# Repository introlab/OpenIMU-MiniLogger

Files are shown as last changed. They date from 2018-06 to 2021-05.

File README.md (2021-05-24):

# OpenIMU-MiniLogger
OpenIMU - Open Hardware Mini Logger based on ESP32. 

Please see also :
[OpenIMU](https://github.com/introlab/OpenIMU) Compatible Sofware.

# Authors
* Dominic Létourneau
* Vincent-Philippe Rhéaume
* Cédric Godin
* Philippe-Olivier Provost
* François Michaud
* Simon Brière
* Mathieu Hamel
* Thomas Godel
* Philippe Boulet

# Pictures
## PCB

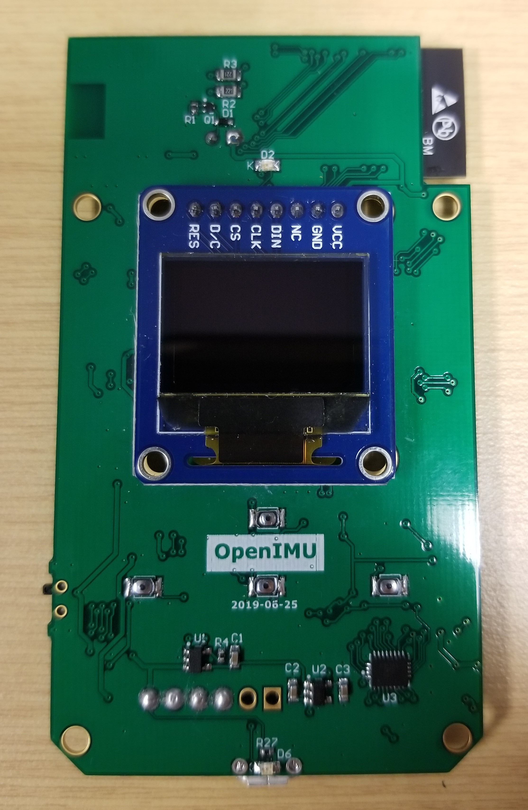
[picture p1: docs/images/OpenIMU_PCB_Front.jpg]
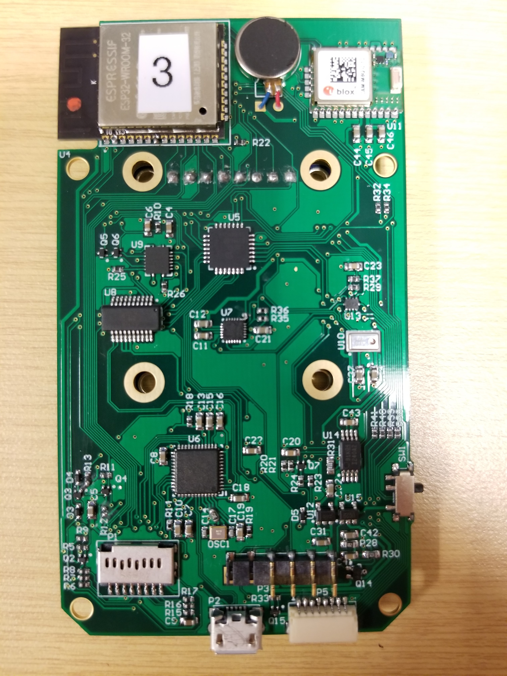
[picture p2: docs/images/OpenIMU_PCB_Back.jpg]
  

## Case and ports

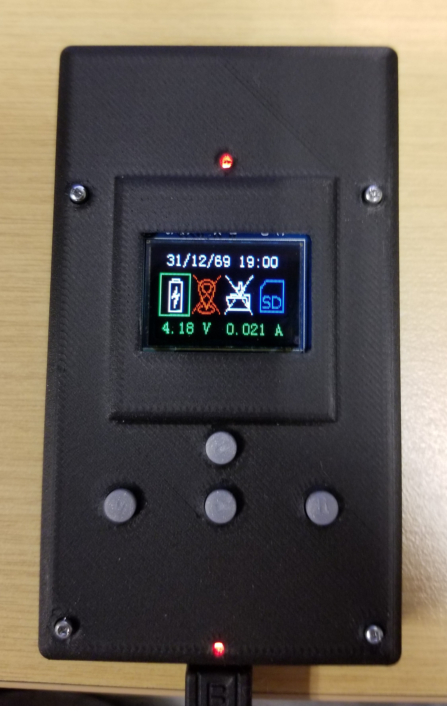
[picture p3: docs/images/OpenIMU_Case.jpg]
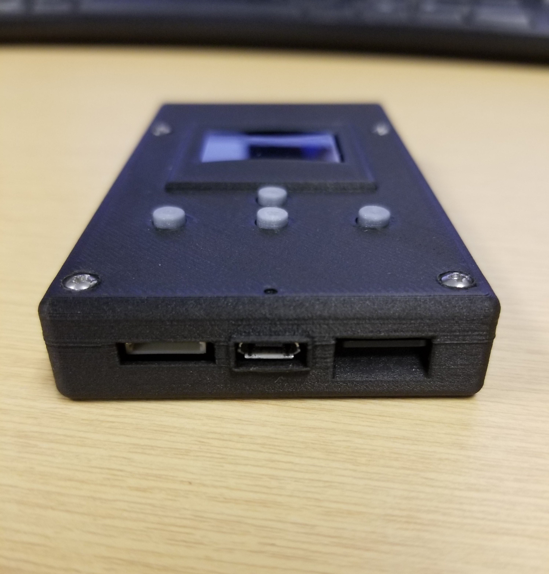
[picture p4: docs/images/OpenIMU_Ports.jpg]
  

## Starting Screen, Main menu and Configuration Menu

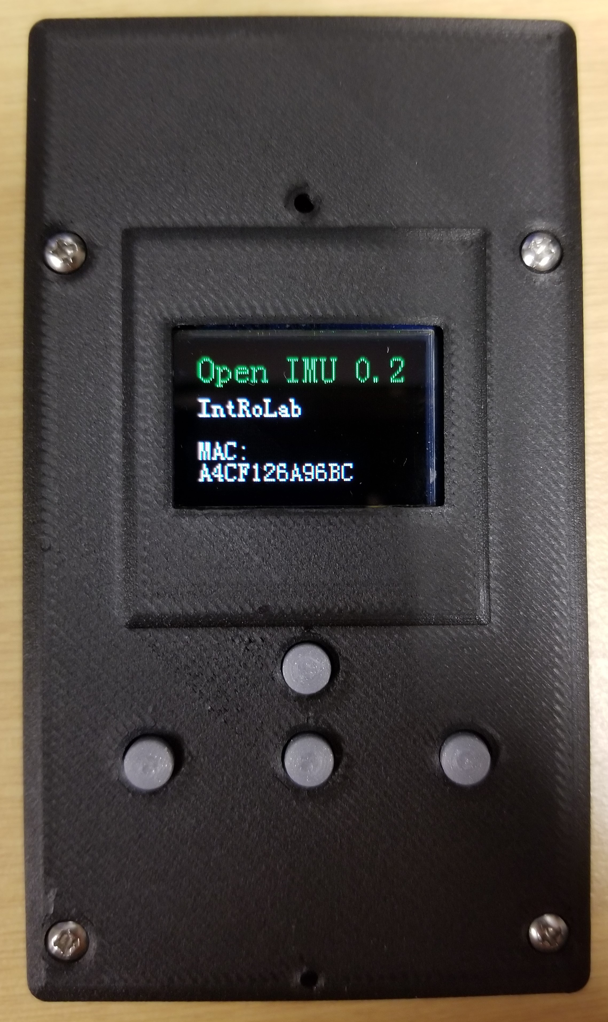
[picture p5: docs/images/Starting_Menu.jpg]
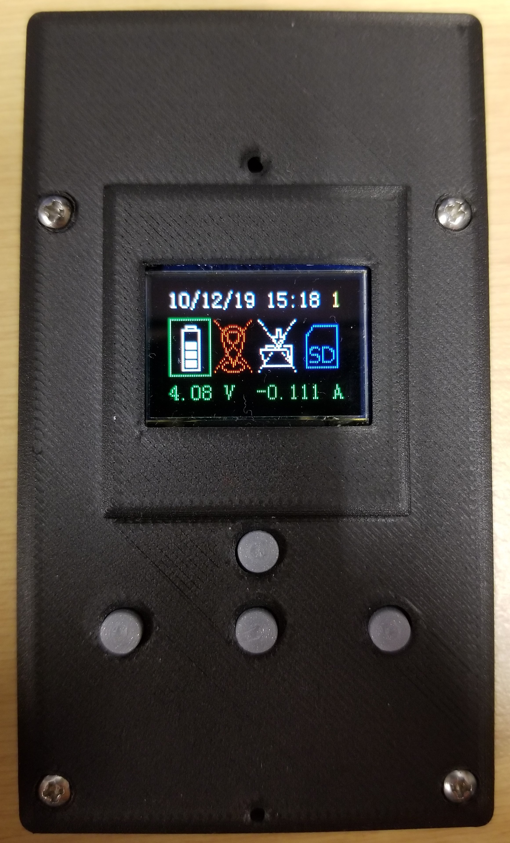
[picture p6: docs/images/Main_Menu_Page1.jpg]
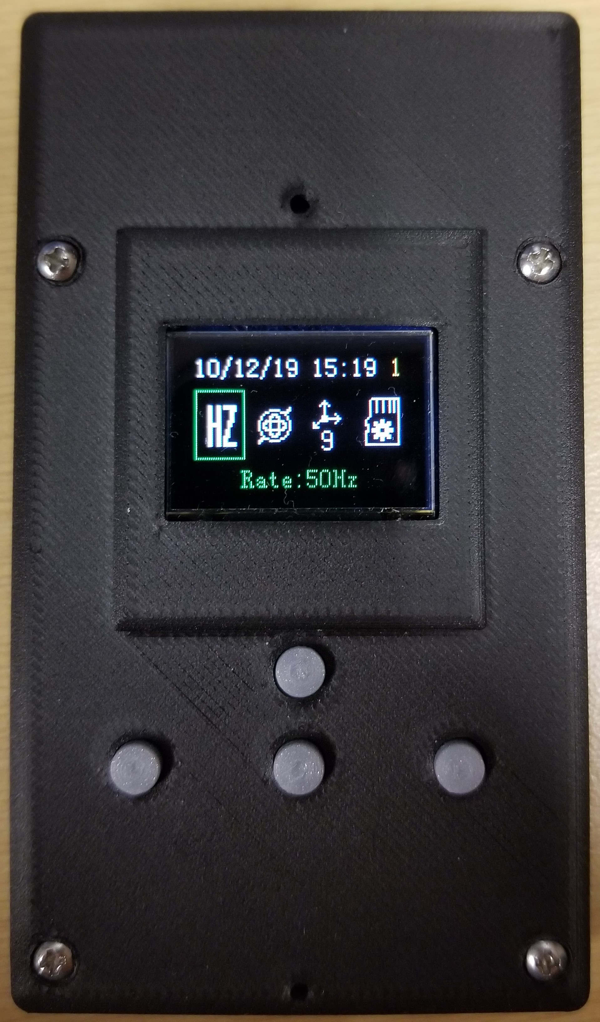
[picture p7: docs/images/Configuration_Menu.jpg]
   

# Features
* [ESP-WROOM-32](https://www.espressif.com/en/esp-wroom-32/resources) based with :
  * [ESP 32 Overview](https://www.espressif.com/en/products/hardware/esp32/overview)
  * WiFi
  * Bluetooth
  * High speed uSD Card Interface (for data logging)
  * High speed USB Mass Storage Interface
  * USB Battery Charger
  * High capacity battery using [Motorala BF5X 1500mA](https://www.battdepot.com/ca/model/cell+phone+battery/motorola/mb525/cmo206.aspx) form factor.
  * Voltage and Current Monitor
  * [9 axis MPU9250 IMU](https://www.invensense.com/products/motion-tracking/9-axis/mpu-9250/)
  * [uBlox CAM-M8Q GPS](https://www.u-blox.com/en/product/cam-m8-series)
  * [NXP / FreeScale MPL115A2 Barometer](https://www.nxp.com/docs/en/data-sheet/MPL115A2.pdf)
  * [WaveShare 0.95" RGB OLED Display](https://www.waveshare.com/wiki/0.95inch_RGB_OLED_(B))
  * [JST JUMPER 08SR-3S](https://www.digikey.ca/product-detail/en/A08SR08SR30K305B/455-3020-ND/6009396/?itemSeq=309204146) connection. with configurable CAN, UART, I2C, Digital I/O.

# Firmware
* Using [PlatformIO](https://platformio.org/)
  * [Arduino](https://github.com/espressif/arduino-esp32) Style (Running in a FreeRTOS Task)
  * Additional use of [FreeRTOS](https://www.freertos.org/) Tasks 

# Schematics & Fab Files
* [Click on this link for AltiumPCB files](./Hardware/AltiumPCB)
* [Schematics](./Hardware/AltiumPCB/Project%20Outputs%20for%20OpenIMU/2019-09-18/OpenIMU.PDF)

# Case & Mechanical Drawings
* [Click on this link for Solidworks and STL files](./Hardware/Solidworks)

## 3D Printing
* [Top Cover STL x1](./Hardware/Solidworks/Top%20Cover.STL)
* [Back Cover STL x1](./Hardware/Solidworks/Back%20Cover%20R2.STL)
* [Button STL x4](./Hardware/Solidworks/Bouton%20Open%20MU.STL)
* [Battery Spacer STL x1](./Hardware/Solidworks/Standoff%20Batterie.STL)

# Building The Project
* Please follow the procedure [here](https://github.com/introlab/OpenIMU-MiniLogger/wiki/Development-Tools).

* [Click on this link to learn how to use the OpenIMU-MiniLogger](./Firmware-Arduino/README.md)

# See Also
* [OpenIMU - Open Source Analysis Software](https://github.com/introlab/OpenIMU)
* [OpenWIMU - Activity Tracker Hardware and Software Platform](https://github.com/introlab/openwimu)

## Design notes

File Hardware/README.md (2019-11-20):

# 3D Model
Only the .stl file are needed to make the case.

Assembly file is available to see the full 3D CAD [model](./Hardware/Solidworks/OpenIMU-MiniLogger.SLDASM) of the case and the PCB.

# External material

* [Screws](https://www.mcmaster.com/92525a118)

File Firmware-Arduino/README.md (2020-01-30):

# User Guide
The OpenIMU-MiniLogger was programmed to be a user friendly device that let you collect data from GPS, IMU, Barometer and more using the grove expansion.

After opening the device using the power switch on the side, the starting menu will appear with different widgets available. You can navigate through them using the "**Next**" and "**Previous**" button and perform their action by **selecting** one. If you reach the end of one page you can switch page by changing widget again. Each widgets possess their own message telling information about the device. The "**Change Menu**" button let you move from the **starting menu** to the **configuration menu**.

The date and time will be updated once the GPS **is fixed**. You can see this information in the GPS widget in the **starting menu**. This only has to be done once or as long as the board is not disconnected from the battery.

## Start Acquiring Data
The OpenIMU-MiniLogger offers data acquisation of multiple sensors for a long period of time. To log information from the GPS, make sure it **is fixed** first. 

### Logging

1. Make sure your device is **open** and there's an **SD card** in the slots. If no SD card is present, you won't be able to log or to connect your device to external (Red icon).
2. **Select** the **folder widget** to start logging. You should see the logging time at the top of the screen appear and the icon turning blue meaning you are logging.
3. To stop logging, simply **select** the same widget again. The icon will get back to its original state and your file will be saved on the SD Card.

Your menu should look like the next picture with the logging time and the ID of your acquisition in your SD card showing at the top.

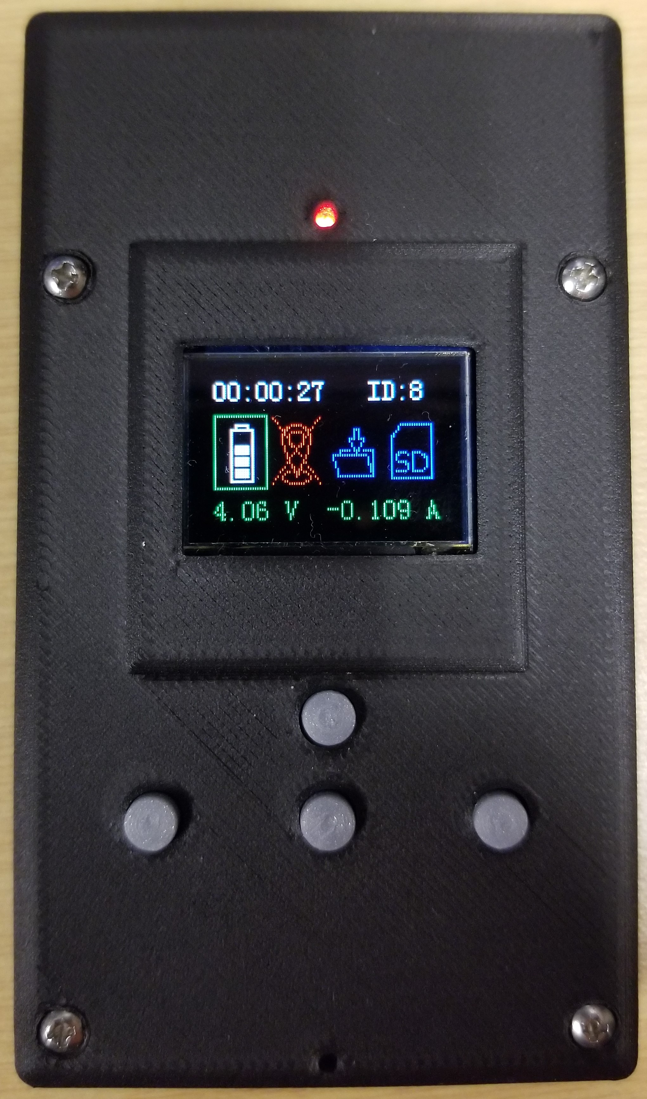
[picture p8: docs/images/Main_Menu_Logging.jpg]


### Transfer File

To process your data using the OpenIMU [software](https://github.com/introlab/OpenIMU):
1. **Plug** your device on your computer with a micro USB cable 
2. **Select** the SD card icon to connect to USB allowing your computer to read the card.
3. Follow the steps in the [OpenIMU project](https://github.com/introlab/OpenIMU) to download and process your data.

### Configuration

The OpenIMU-MiniLogger allows changeable configuration for your data acquisition. These parameter can be changed using the [ConfigAPP](../ConfigAPP/README.md) created for this purpose or inside the device itself with the configuration menu:

1. From the home screen, press the "**Change Menu**" button to go to the configuration menu.
2. Different widget are available to change parameters of the IMU:
    1. Sample rate (10,50,100,200 Hz)
    2. Gyroscope range (250,500,1000,2000 dps)
    3. Accelerometer range (2,4,8,16 g).
3. **Select** the widget to switch between the possibilities.

The fourth widget tells you the space left on the SD card.

**_Note:_** _The device is slower when the IMU sample Rate is at 200Hz. Data acquisition is still possible but the refresh rate of the screen will be slower_

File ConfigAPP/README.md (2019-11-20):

# Configuration App

This application let you configure the OpenIMU-MiniLogger by modifying a .json file inside the SD card.

## IMU Config

In the IMU tab, you can choose which parameter you want to change to one of the proposed value.

1. **Open** the [OpenIMU App](https://github.com/introlab/OpenIMU)
2. Make sure your device **is connected** and the SD card **is readable** through the micro USB cable.
3. **Select** the option you want.
4. **Save** your configuration.
5. **Start** logging with your configured device.

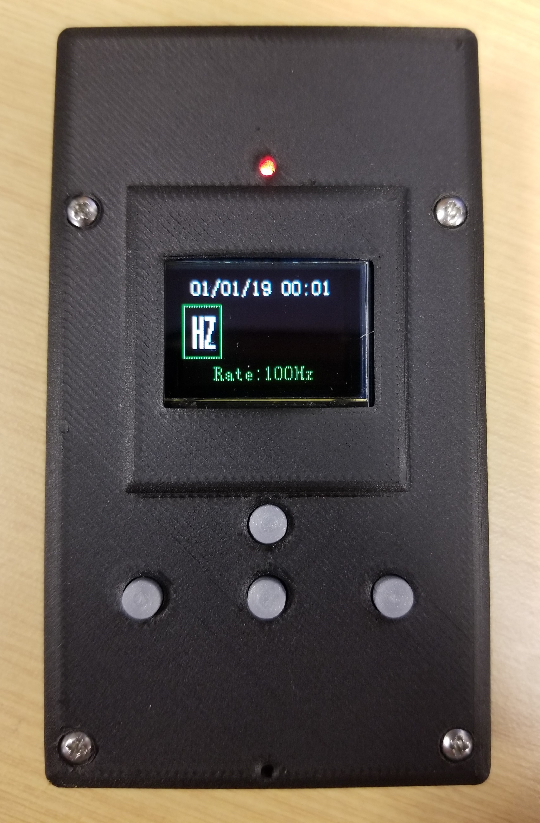
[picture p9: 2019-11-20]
docs/images/Config_Menu.jpg

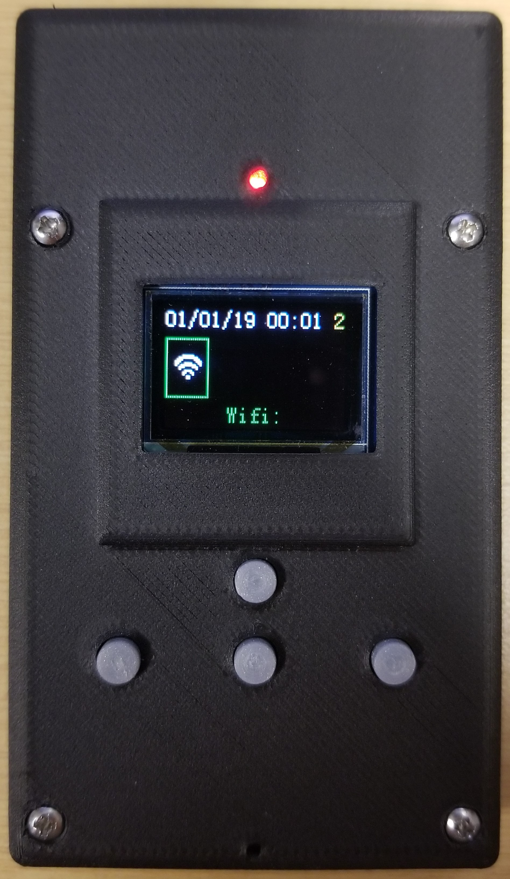
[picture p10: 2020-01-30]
docs/images/Main_Menu_Page2.jpg

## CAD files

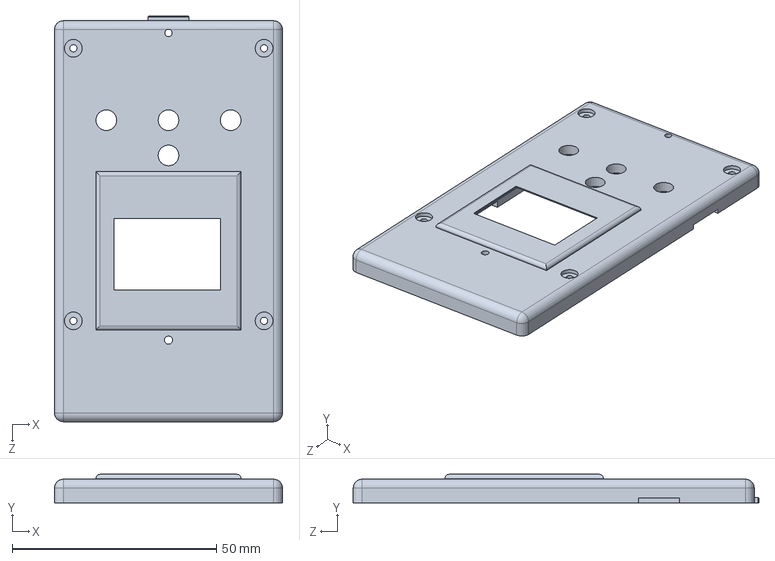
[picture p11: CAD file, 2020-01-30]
Hardware/Solidworks/Back Cover R2.SLDPRT
55.9 x 6.99 x 99.4 mm

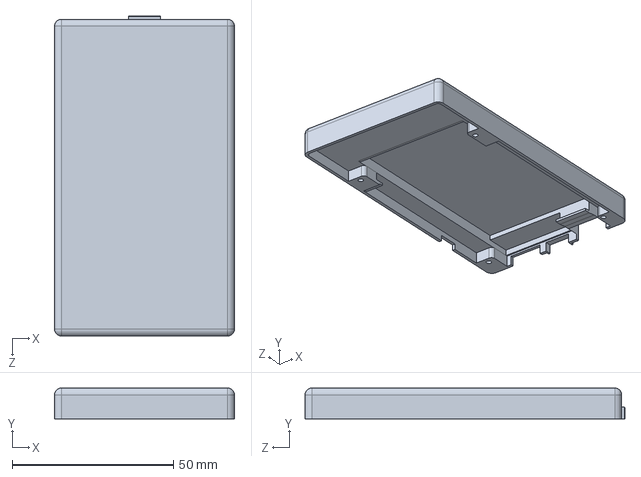
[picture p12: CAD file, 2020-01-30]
Hardware/Solidworks/Top Cover.SLDPRT
55.9 x 9.62 x 99.3 mm

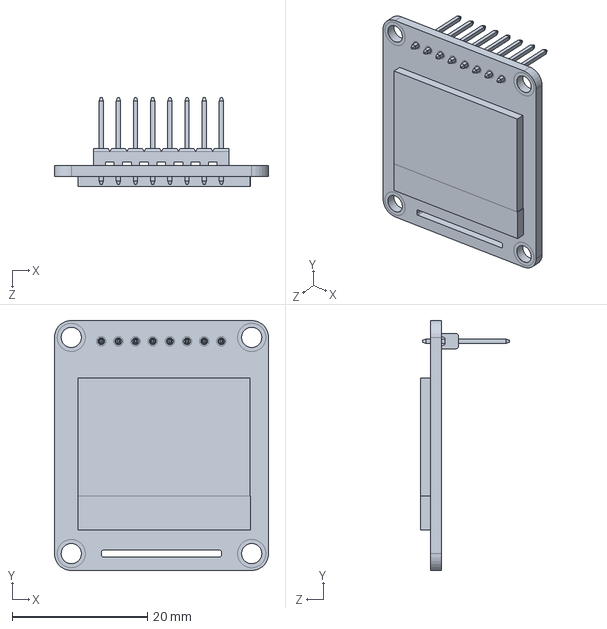
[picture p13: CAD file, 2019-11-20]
Hardware/Solidworks/OLED_RGB_0.95_96x64_Waveshare.SLDPRT
31.7 x 37.0 x 13.1 mm

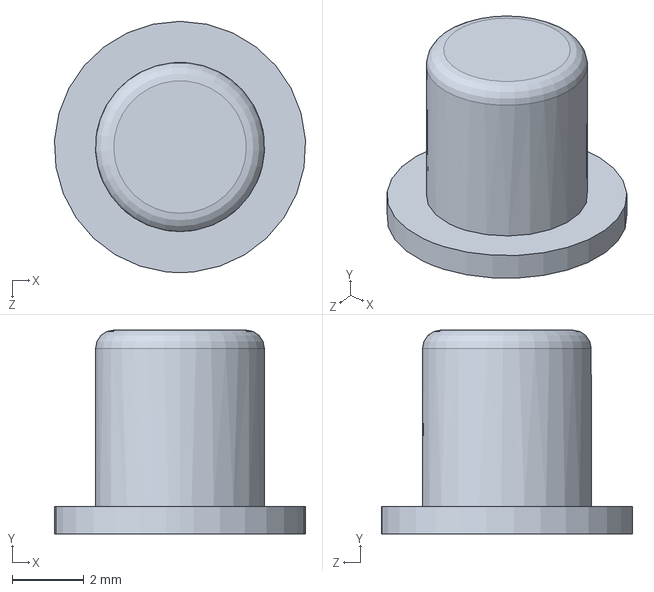
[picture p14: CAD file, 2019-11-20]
Hardware/Solidworks/Bouton Open IMU.SLDPRT
6.97 x 5.66 x 6.98 mm

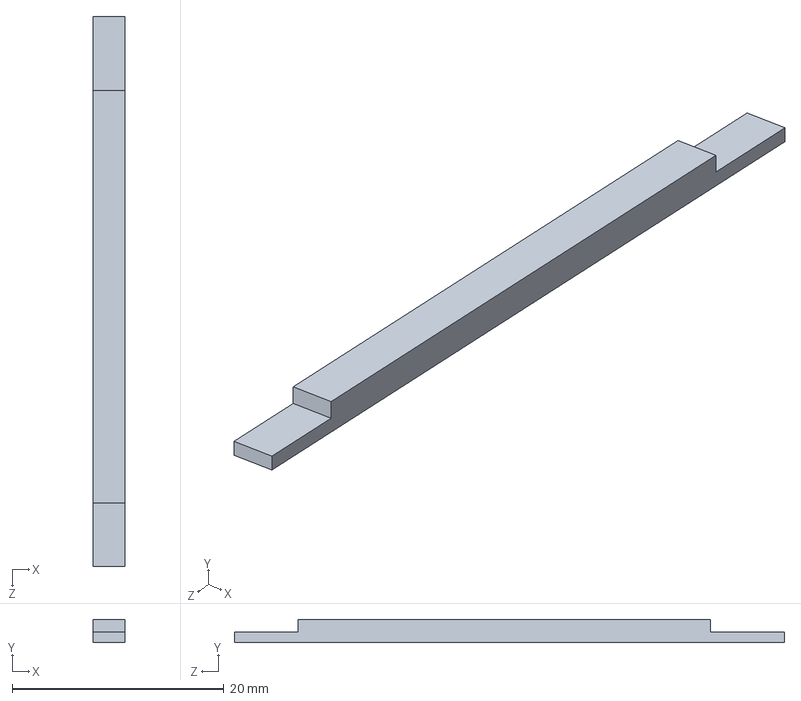
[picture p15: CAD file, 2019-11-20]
Hardware/Solidworks/Standoff Batterie.SLDPRT
3.00 x 2.20 x 52.0 mm

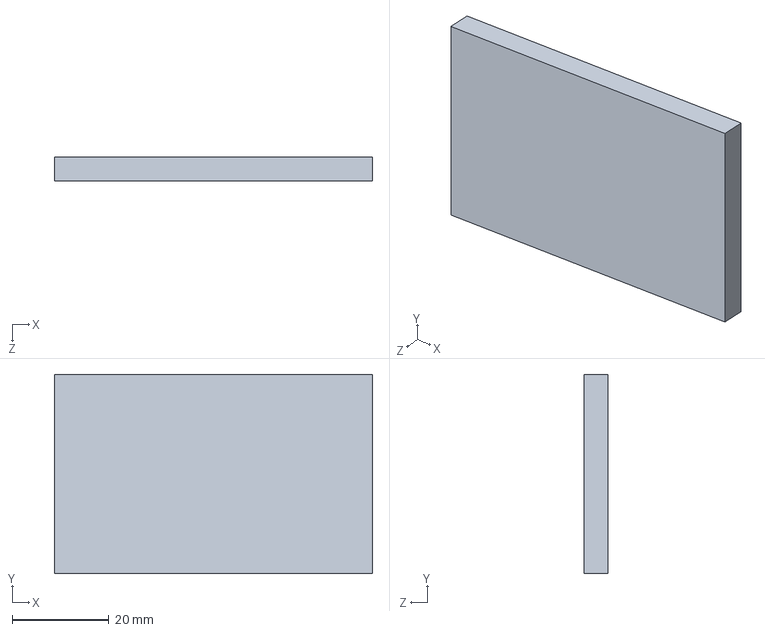
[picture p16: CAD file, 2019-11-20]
Hardware/Solidworks/Battery.SLDPRT
65.8 x 41.2 x 5.00 mm

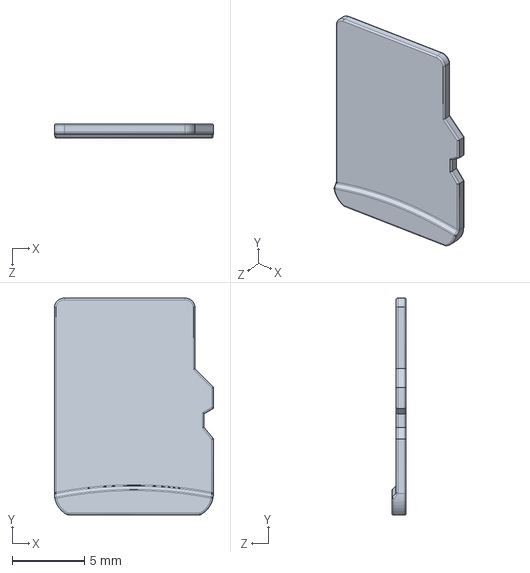
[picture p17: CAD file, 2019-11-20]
Hardware/Solidworks/Micro SD Cardtrue.SLDPRT
11.0 x 15.0 x 1 mm

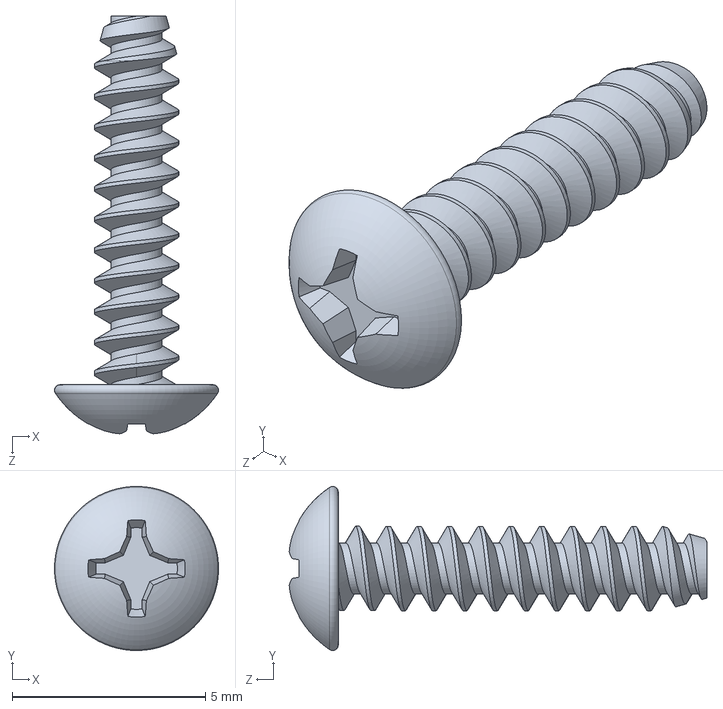
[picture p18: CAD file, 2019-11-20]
Hardware/Solidworks/92525A118_THREAD-FORMING SCREW FOR SHEET METAL IRON.SLDPRT
4.24 x 4.24 x 10.8 mm

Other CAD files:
Hardware/Solidworks/Back Cover R2.STL
Hardware/Solidworks/Bouton Open IMU.STL
Hardware/Solidworks/Standoff Batterie.STL
Hardware/Solidworks/Top Cover.STL

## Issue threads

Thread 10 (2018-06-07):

Reset when connecting to USB Port on Windows

doumdi, 2018-06-07:
The module resets when connecting to Windows due to USB serial port initialization / enumeration playing with DTR / RTS signals. This could be avoided by disconnecting the reset signal from the USB to UART chip when we do not want to reset.

doumdi, 2019-11-20:
Done.

Closed 2019-11-20.

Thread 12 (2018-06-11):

USB hub does not communicate when plugged in; crystal oscillator problem

vrheaume, 2018-06-11:
1 Meg resistor should be added to design between OSC1 pins.

Modification has been tested as a rework/patch.

Closed 2019-10-22.

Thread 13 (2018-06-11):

USB Card reader does not detect card insertion

vrheaume, 2018-06-11:
This bug stems from an interaction between two features:

1) For the USB Card reader (USB264x) to work properly with the SD card switch (FSSD07), it was necessary to "mask" the Card Detect signal until FSSD07 is switched to USB Card reader mode. This is done with transistor Q3.
2) However, USB Card reader "CARD_POWER" voltage regulator is OFF until a card is detected, thus Q3 can not conduct.

Pulling R12 to "+3V3" instead of "1_VDD" fixes this bug, this change should be integrated in the design.

Closed 2019-10-22.

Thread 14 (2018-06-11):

Hardware components around e-ink display's high-voltage regulators should be >20V-tolerant

vrheaume, 2018-06-11:
The display generates high-voltage to function. Initially a 20V transistor was chosen according to measurement that had been done previously, but assembly of more units showed several reliability problems that were fixed by switching to a 25V transistor.

More investigation/probing should be done to ensure that the transistor rating is respected at all times. The e-ink display datasheet does not clearly mention how high the voltage can be. A new transistor should be specified in the BOM.

Closed 2019-10-22.

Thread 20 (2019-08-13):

OpenIMU USB hub disapears from Ubuntu

GodCed, 2019-08-13:
OpenIMU USB hub disapears from Ubuntu from time to time.
Seems to be often after programming, sometime after reset with the power switch.

It is necessary to rebind the USB bus in Ubuntu (unplugging and re-plugging is not sufficient) to recover.
For USB 3.0 bus:
```bash
sudo echo -n "0000:03:00.0" | sudo tee /sys/bus/pci/drivers/xhci_hcd/unbind
sudo echo -n "0000:03:00.0" | sudo tee /sys/bus/pci/drivers/xhci_hcd/bind
```

doumdi, 2019-11-20:
Fixed.

Closed 2019-11-20.

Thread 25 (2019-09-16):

Create a configuration file on device (SD card)

doumdi, 2019-09-16:
JSON to be documented. Example :

{
 "OpenTeraServer": "telesante.3it.usherbrooke.ca"
"OpenTeraServerPort": 4040
 "IMU": 50
"Power": 1
}

doumdi, 2019-09-16:
Pars JSON files in the firmware with : https://github.com/espressif/esp-idf/tree/master/components/json ?

doumdi, 2019-09-16:
Each device on the PCB should have "useful" parameters.

doumdi, 2019-11-20:
Wlroing.

Closed 2019-11-20.

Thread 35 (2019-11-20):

Vibration motor should be powered by VBAT instead of 3V3.

doumdi, 2019-11-20:
Next PCB version.

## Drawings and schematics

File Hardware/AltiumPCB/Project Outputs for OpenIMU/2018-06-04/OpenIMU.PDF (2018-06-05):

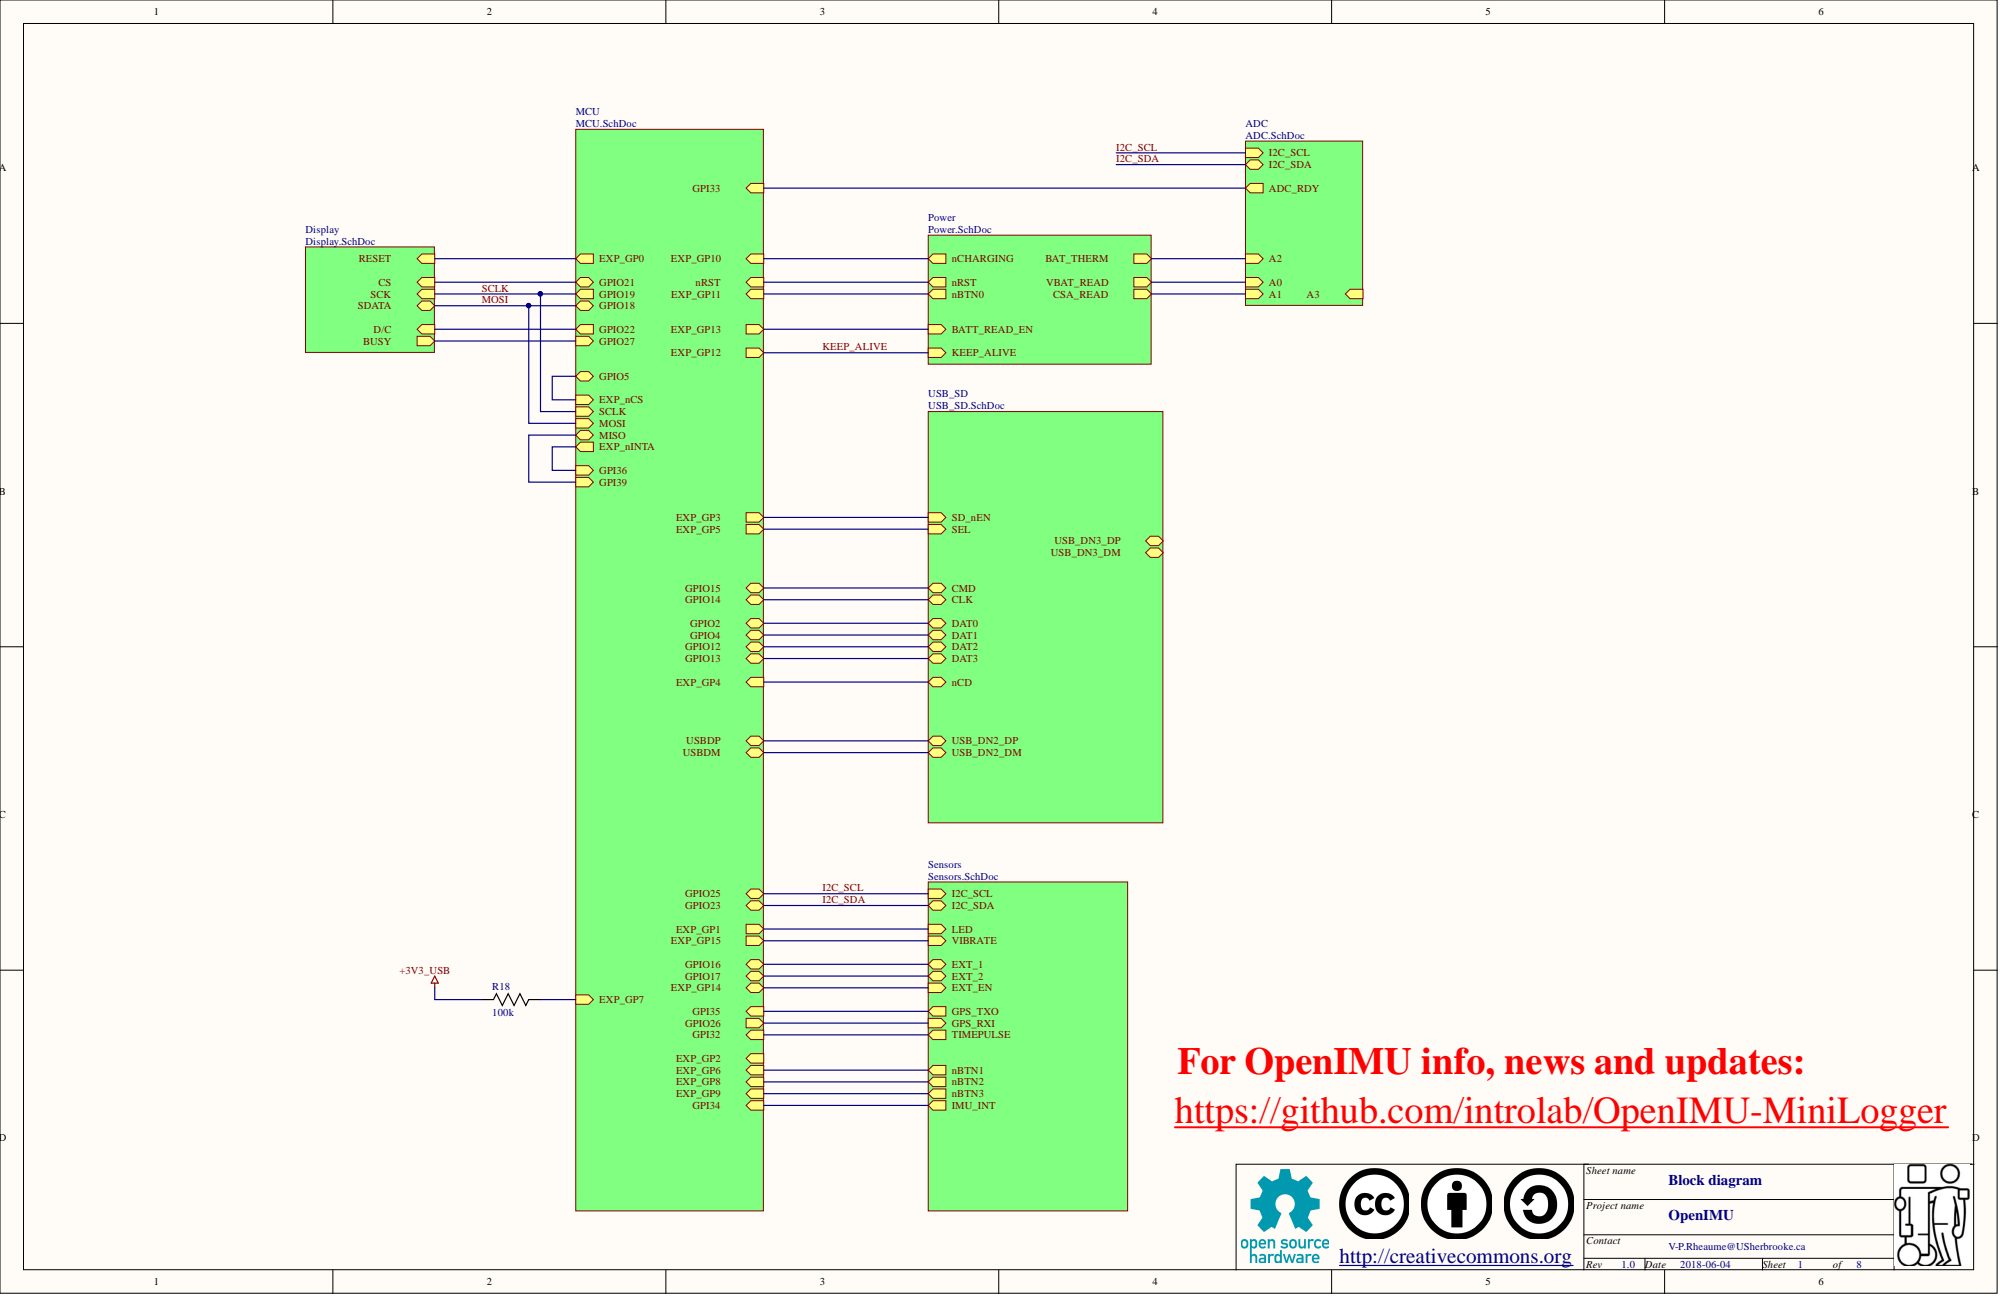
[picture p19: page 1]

For OpenIMU info, news and updates:
https://github.com/introlab/OpenIMU-MiniLogger

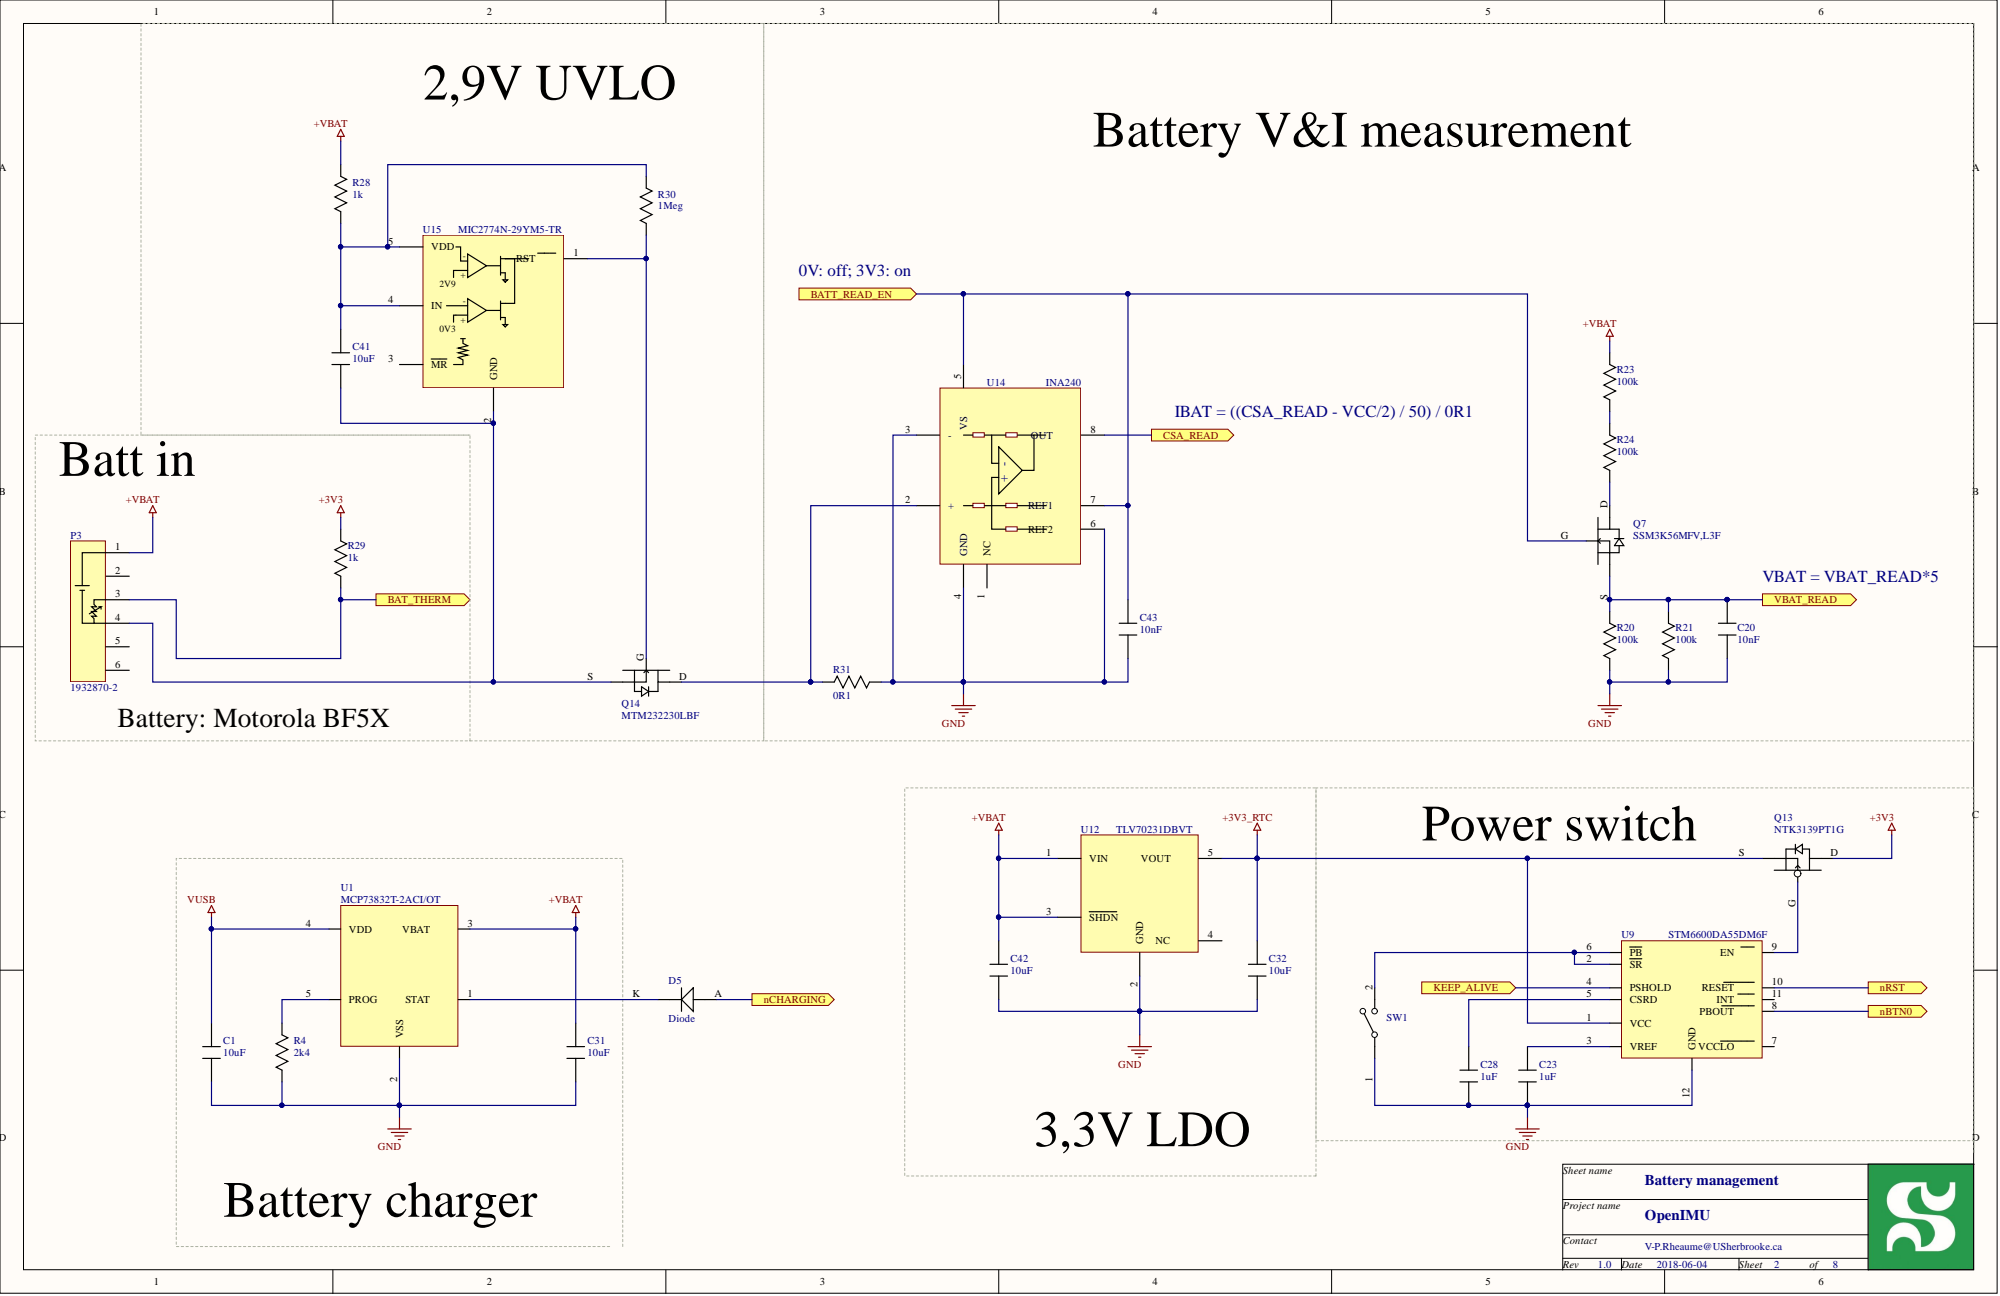
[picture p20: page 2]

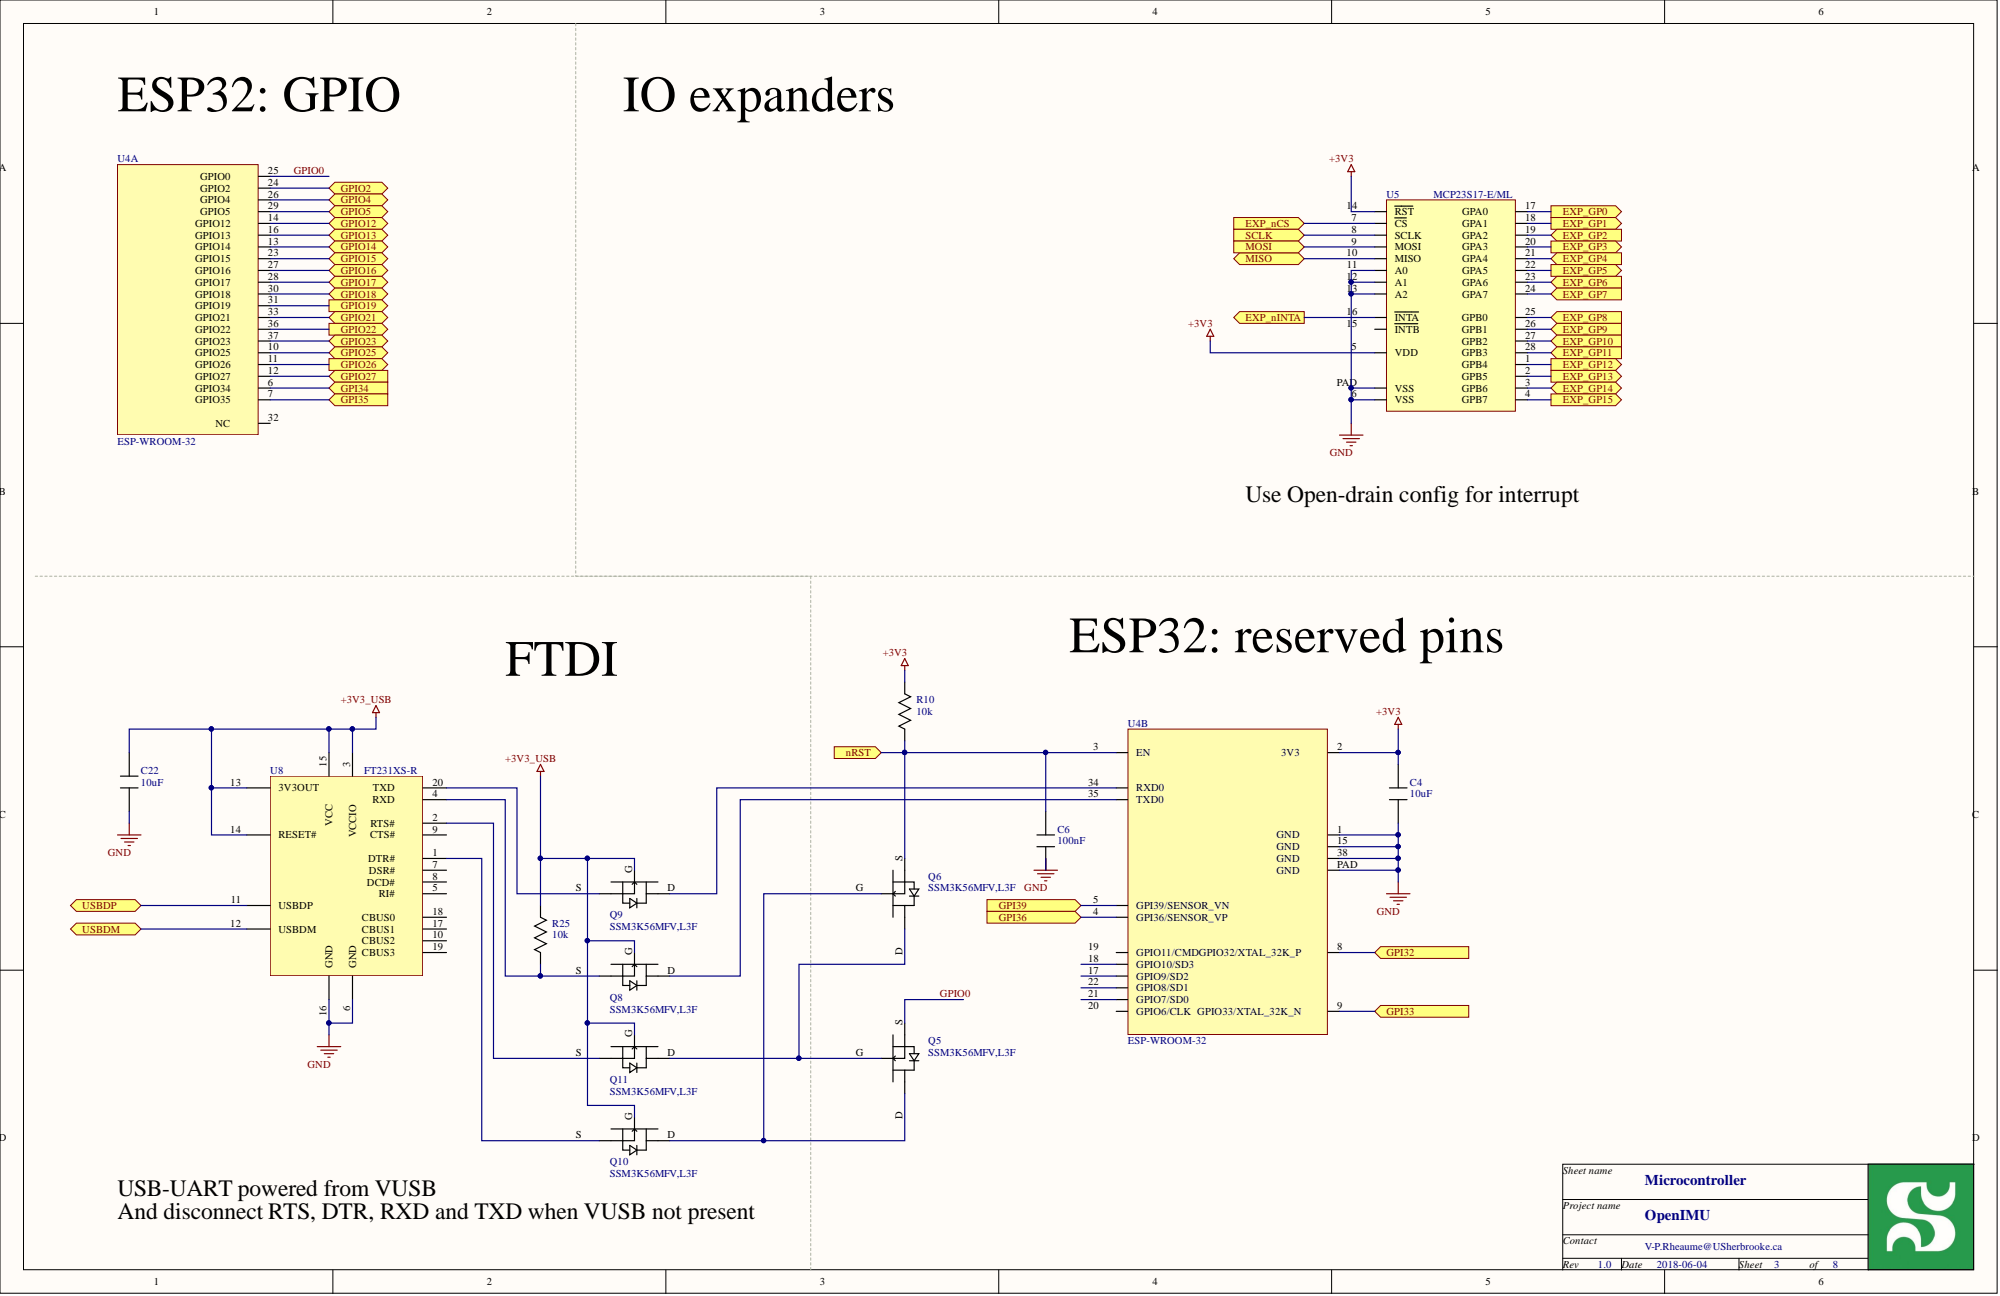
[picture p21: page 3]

Use Open-drain config for interrupt

USB-UART powered from VUSB
And disconnect RTS, DTR, RXD and TXD when VUSB not present

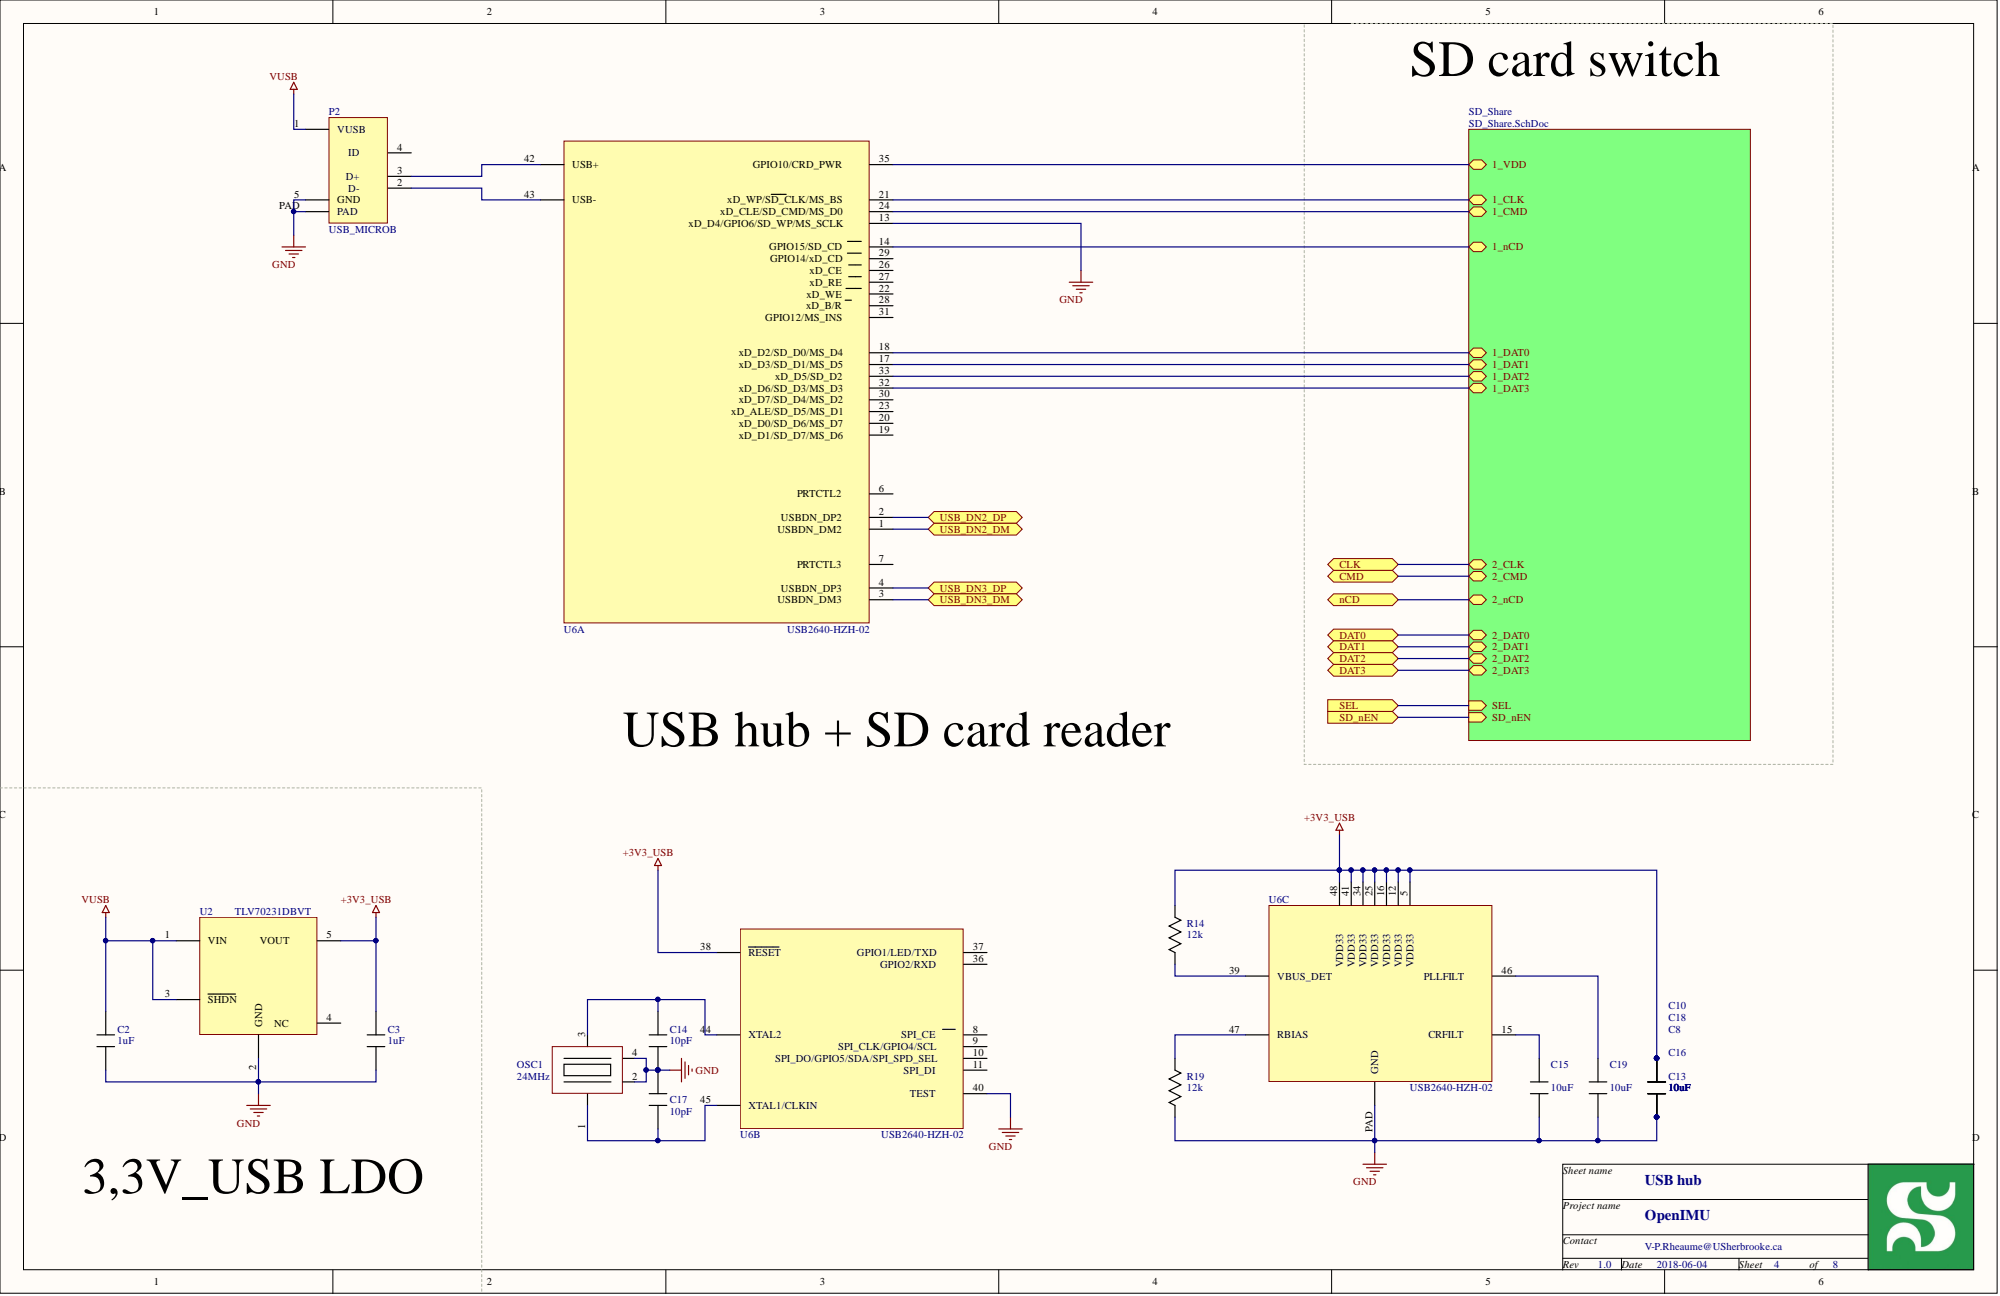
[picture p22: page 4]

USB hub + SD card reader

CRFILT

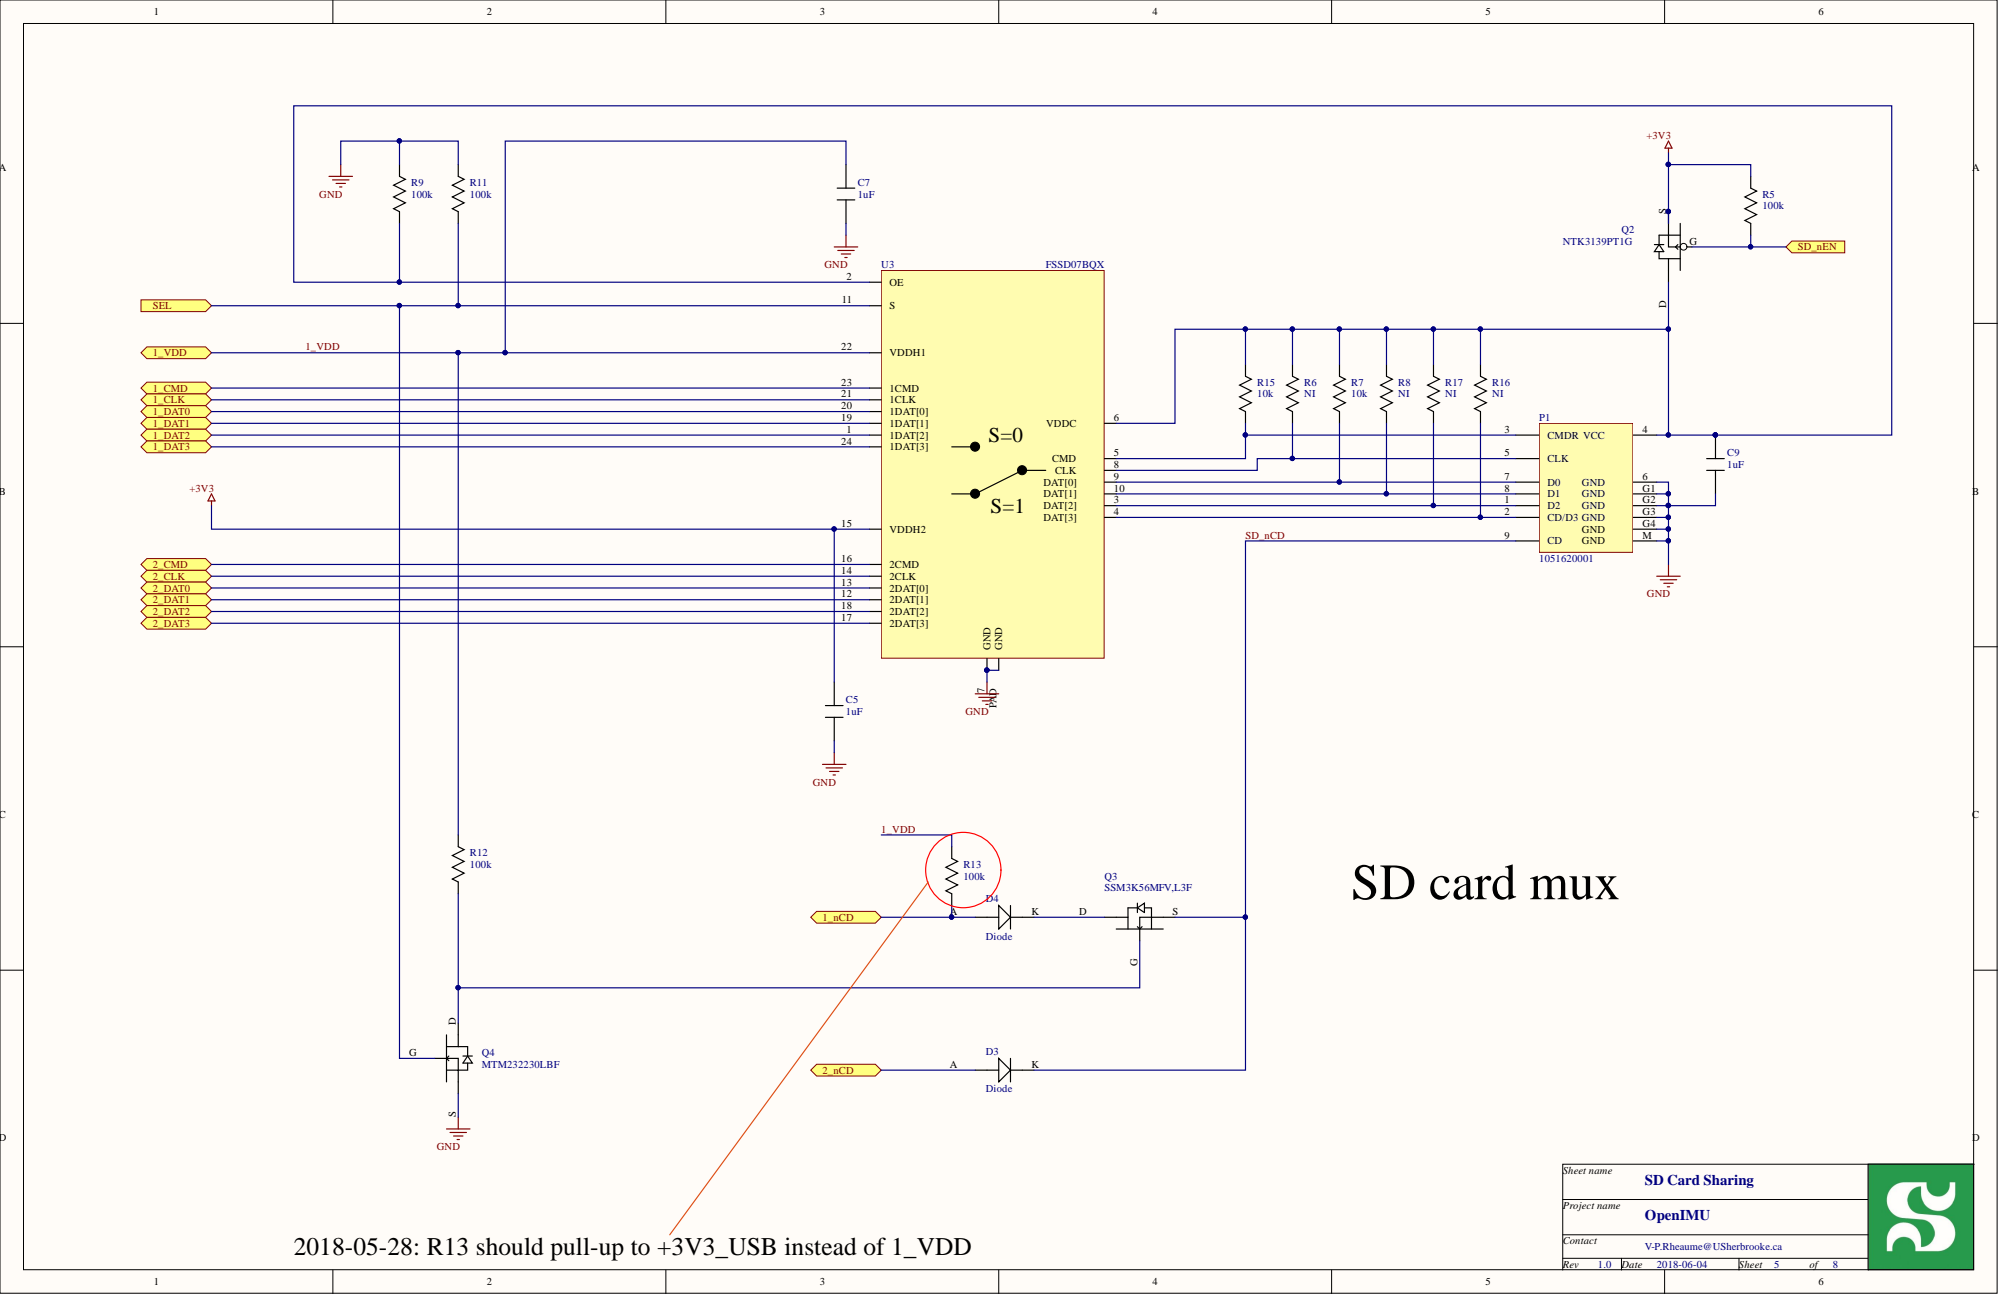
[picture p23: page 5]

2 3
2 1
2 0

1 0 | | | 8 | | G 1
3 | | 1 | | G 2

1 4
1 3
1 2
1 8
1 7

2018-05-28: R13 should pull-up to +3V3_USB instead of 1_VDD

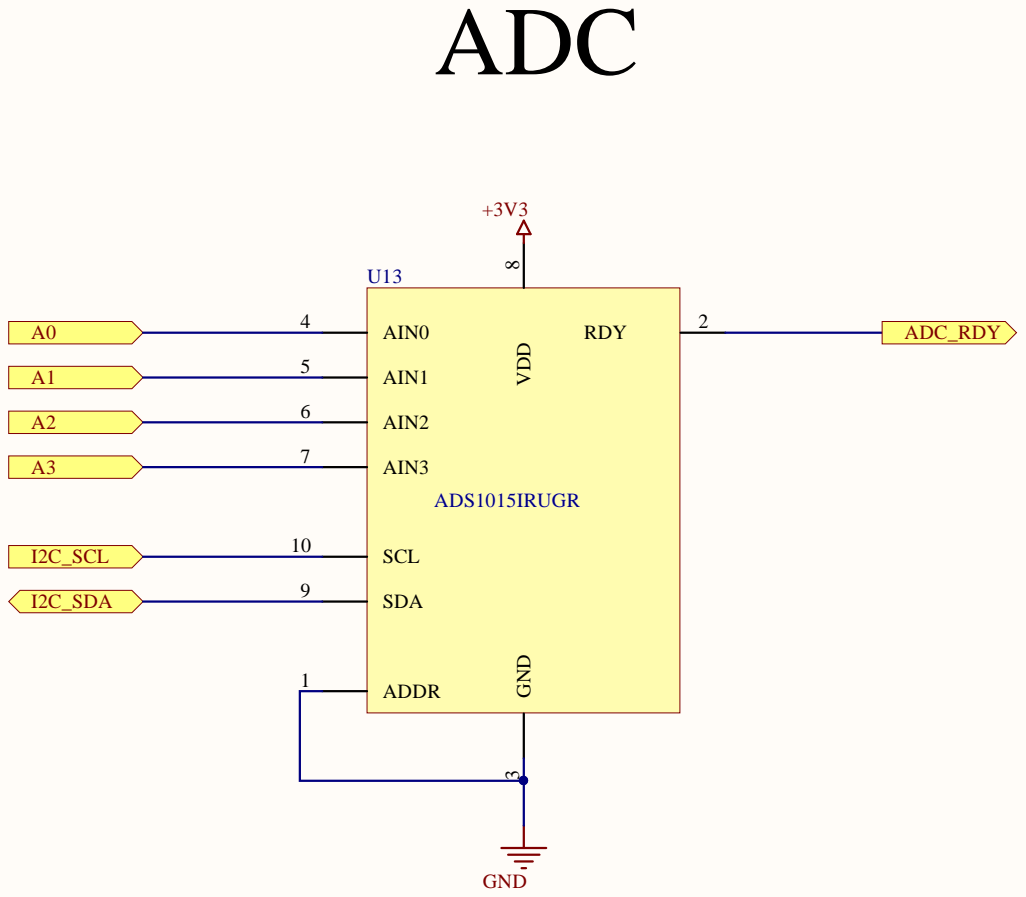
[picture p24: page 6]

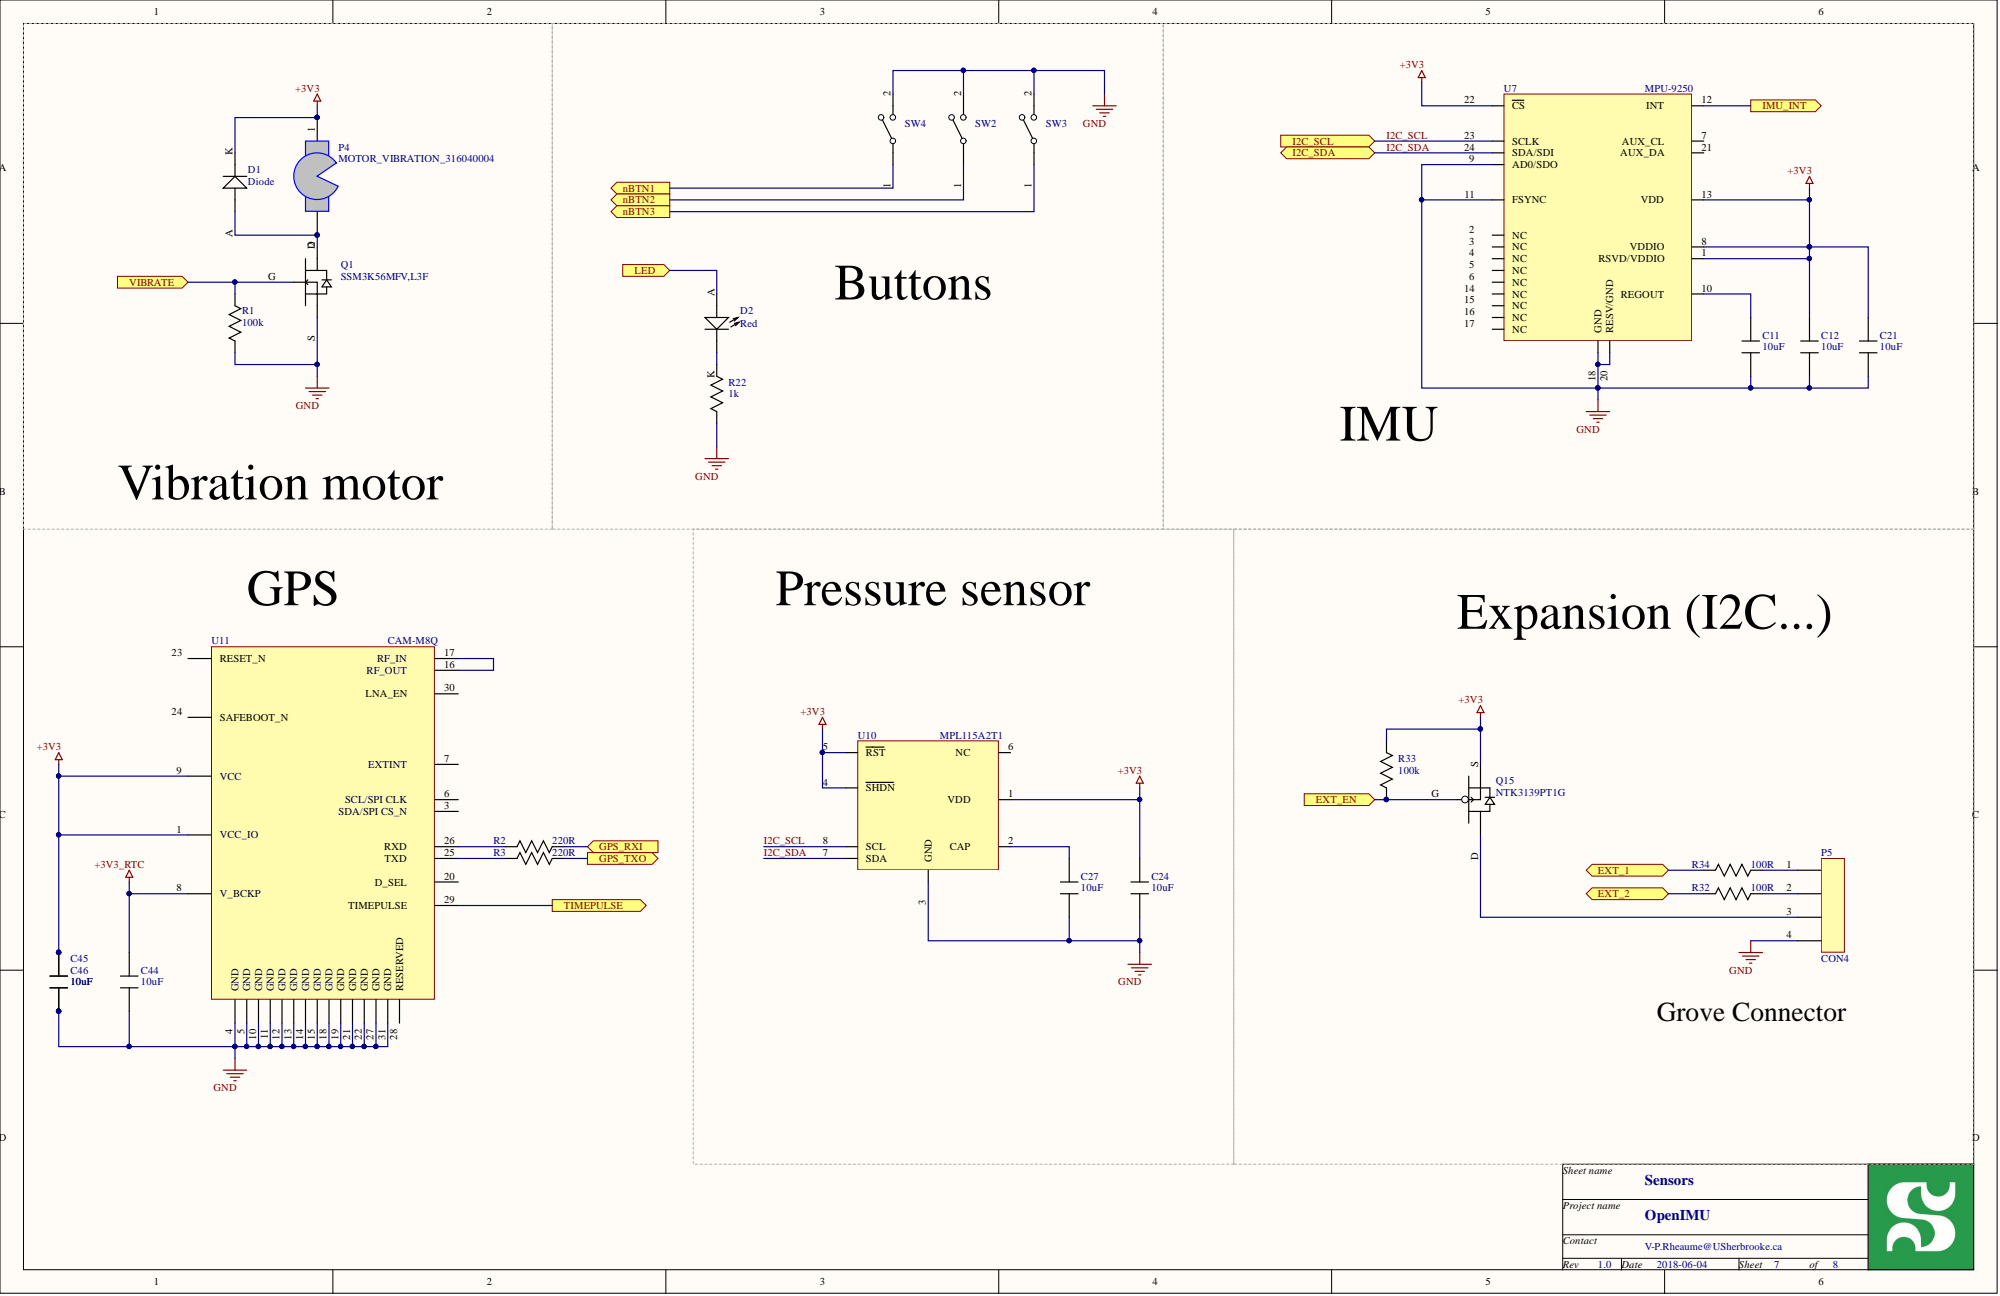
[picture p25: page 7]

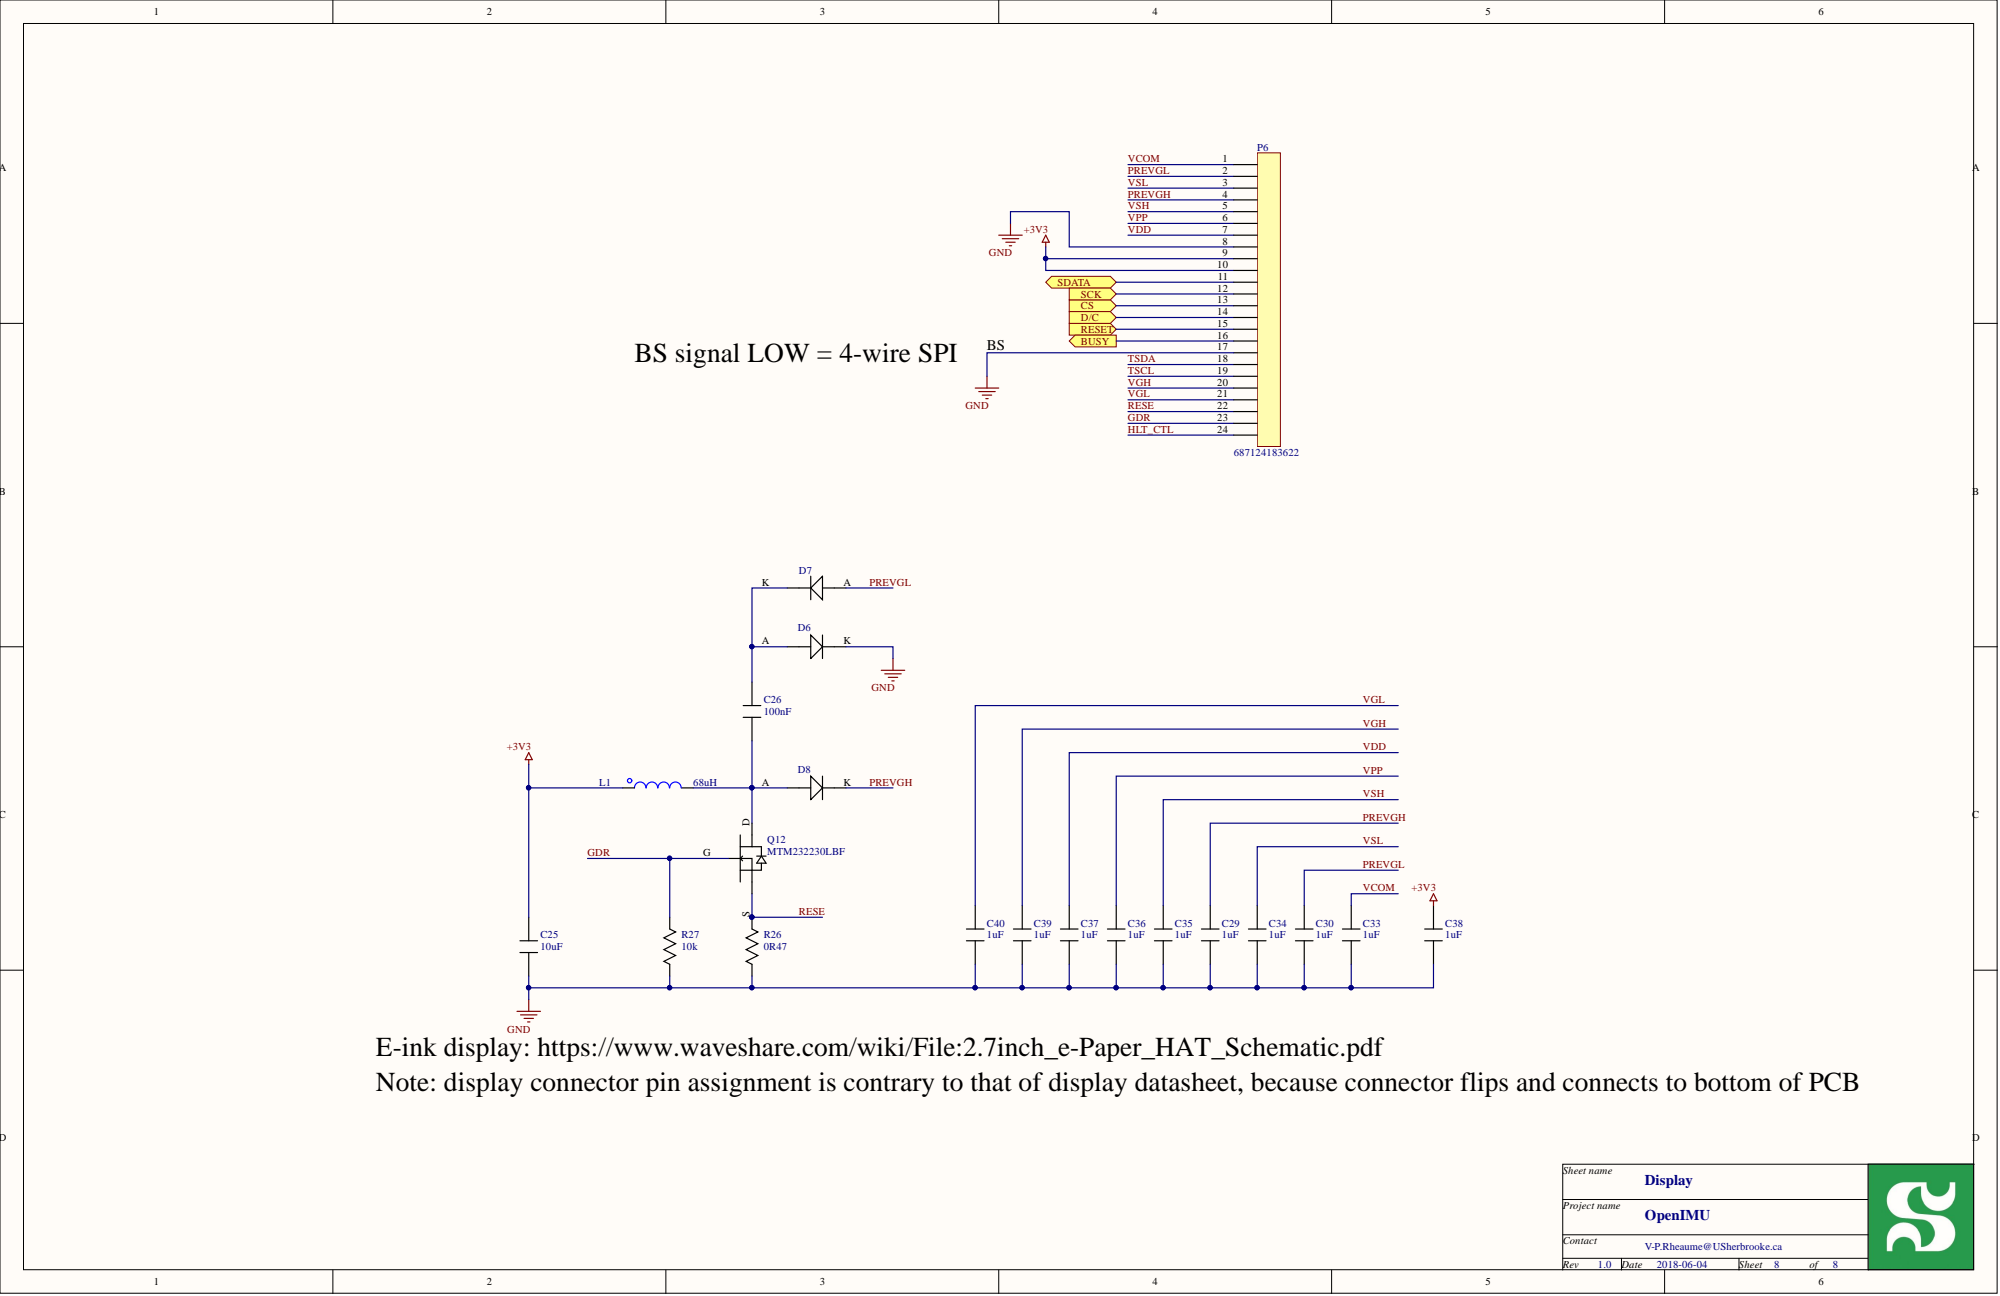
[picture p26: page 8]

VPP 6 +3V3 VDD 7 8

10

BS signal LOW = 4-wire SPI

E-ink display: https://www.waveshare.com/wiki/File:2.7inch_e-Paper_HAT_Schematic.pdf
Note: display connector pin assignment is contrary to that of display datasheet, because connector flips and connects to bottom of PCB

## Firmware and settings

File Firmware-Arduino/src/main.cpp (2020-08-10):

#include <Arduino.h>

#include <stdio.h>
#include <string.h>
#include <iostream>
#include <sstream>
#include <iomanip>
#include "freertos/FreeRTOS.h"
#include "freertos/task.h"
#include "esp_system.h"
#include "esp_wifi.h"
#include "driver/spi_master.h"
#include "soc/gpio_struct.h"
#include "driver/gpio.h"
#include "driver/i2c.h"
#include <soc/efuse_reg.h>

#include "ioexpander.h"
#include "power.h"
#include "spibus.h"
#include "i2cbus.h"
#include "display.h"
#include "imu.h"
#include "sdcard.h"
#include "barometer.h"
#include "gps.h"
#include "pulse.h"
#include "wifitransfer.h"

#include "buttons.h"
#include "widget/widget.h"
#include "widget/battery.h"
#include "widget/gps.h"
#include "widget/log.h"
#include "widget/sd.h"
#include "widget/samplerate.h"
#include "widget/gyrorange.h"
#include "widget/accelrange.h"
#include "widget/SDfreespace.h"
#include "widget/wifitransfer.h"
#include "homescreen.h"
#include "configmanager.h"

namespace Actions
{
    bool loggingEnabled = false;
    bool wasLogging = false;
    bool sdcardExternal = false;
    int SampleRateCounter = 1;
    int GyroRangeCounter = 1;
    int AccelRangeCounter = 1;

    void SDToESP32()
    {
        if (loggingEnabled)
        {
            loggingEnabled = false;
            SDCard::instance()->stopLog();  
        }
        sdcardExternal = false;
        SDCard::instance()->toESP32();
        //Reload configuration, user may have changed it from its computer.
        ConfigManager::instance()->load_configuration();
    }

    void SDToExternal()
    {
        if (SDCard::instance()->getSdCardPresent())
        {
            if (loggingEnabled)
            {
                loggingEnabled = false;
                SDCard::instance()->stopLog();  
            }
            sdcardExternal = true;
            SDCard::instance()->toExternal();
        }
    }

    void ToggleSD()
    {
        if (sdcardExternal)
        {
            SDToESP32();
        }
        else
        {
            SDToExternal();
        }
        
    }

    //Same function to start and stop logging to avoid double start
    void IMUStartSD()
    {
        printf("IMUStartSD\n");
        if (loggingEnabled )
        {
            printf("Stopping log\n");
            loggingEnabled = false;
            sdcardExternal = false;
            SDCard::instance()->stopLog();
        }
        else if (SDCard::instance()->getSdCardPresent())
        {
            printf("Starting log\n");
            loggingEnabled = true;
            sdcardExternal = false;
            SDCard::instance()->startLog();
        }
        else
        {
            printf("No Sd Card found\n");
        }
        
    }
    //Fonction to Change the sample rate of the IMU
    void ChangeSampleRate()
    {   
        if(!loggingEnabled)
        {
            //Get actual configuration
            IMUconfig_Sd config = ConfigManager::instance()->getIMUConfig();

            if(SampleRateCounter==1)
            {
                config.IMUSampleRate = 50;
                IMU::instance()->setSampleRate(50);
                SampleRateCounter++;
            }
            else if(SampleRateCounter==2)
            {
                config.IMUSampleRate = 100;
                IMU::instance()->setSampleRate(100);
                SampleRateCounter++;
            }
            else if(SampleRateCounter==3)
            {
                config.IMUSampleRate = 200;
                IMU::instance()->setSampleRate(200);
                SampleRateCounter++;
            }
            else if(SampleRateCounter==4)
            {
                config.IMUSampleRate = 10;
                IMU::instance()->setSampleRate(10);
                SampleRateCounter=1;
            }

            //Update configuration
            ConfigManager::instance()->setIMUConfig(config);

            //Save config
           
            if (ConfigManager::instance()->save_configuration())
            {
                printf("Configuration saved!\n");
            }
            else
            {
                printf("Error! Configuration not saved!\n");
            }
        }
        else
        {
            printf("Can't change sample rate while logging\n");
        }
        
    }

    //Fonction to Change the Gyroscope Range of the IMU
    void ChangeGyroRange()
    {   
        if(!loggingEnabled)
        {
            //Get actual configuration
            IMUconfig_Sd config = ConfigManager::instance()->getIMUConfig();

            if(GyroRangeCounter==1)
            {
                config.IMUGyroRange = 500;
                IMU::instance()->setGyroRange(500);
                GyroRangeCounter++;
            }
            else if(GyroRangeCounter==2)
            {
                config.IMUGyroRange = 1000;
                IMU::instance()->setGyroRange(1000);
                GyroRangeCounter++;
            }
            else if(GyroRangeCounter==3)
            {
                config.IMUGyroRange = 2000;
                IMU::instance()->setGyroRange(2000);
                GyroRangeCounter++;
            }
            else if(GyroRangeCounter==4)
            {
                config.IMUGyroRange = 250;
                IMU::instance()->setGyroRange(250);
                GyroRangeCounter=1;
            }

            //Update configuration
            ConfigManager::instance()->setIMUConfig(config);

            //Save config
            if (ConfigManager::instance()->save_configuration())
            {
                printf("Configuration saved!\n");
            }
            else
            {
                printf("Error! Configuration not saved!\n");
            }
        }
        else
        {
            printf("Can't change gyroscope range while logging\n");
        }
        
    }

    //Fonction to Change the Accelerometer Range of the IMU
    void ChangeAccelRange()
    {   
        if(!loggingEnabled)
        {
            //Get actual configuration
            IMUconfig_Sd config = ConfigManager::instance()->getIMUConfig();

            if(AccelRangeCounter==1)
            {
                config.IMUAcellRange = 4;
                IMU::instance()->setAccelRange(4);
                AccelRangeCounter++;
            }
            else if(AccelRangeCounter==2)
            {
                config.IMUAcellRange = 8;
                IMU::instance()->setAccelRange(8);
                AccelRangeCounter++;
            }
            else if(AccelRangeCounter==3)
            {
                config.IMUAcellRange = 16;
                IMU::instance()->setAccelRange(16);
                AccelRangeCounter++;
            }
            else if(AccelRangeCounter==4)
            {
                config.IMUAcellRange = 2;
                IMU::instance()->setAccelRange(2);
                AccelRangeCounter=1;
            }

            //Update configuration
            ConfigManager::instance()->setIMUConfig(config);

            //Save config
            if (ConfigManager::instance()->save_configuration())
            {
                printf("Configuration saved!\n");
            }
            else
            {
                printf("Error! Configuration not saved!\n");
            }
        }
        else
        {
            printf("Can't change Accelerometer range while logging\n");
        }
        
    }
    
    void WifiActions()
    {
        //Action of the wifi
        WiFiTransfer::instance()->start_transfer();
    }
}

void ledBlink(void *pvParameters)
{

    //Initialize last tick
    TickType_t _lastTick = xTaskGetTickCount();

    int state = LOW;

    while(1)
    {
        //2Hz
        vTaskDelayUntil(&_lastTick, 500 / portTICK_RATE_MS);
        IOExpander::instance()->digitalWrite(EXT_PIN01_LED, state);
        state = !state;
        
    }
}

//Activate the vibrating motor for the time asked
void VibrateMotor(int vibrate_time)
{
    IOExpander::instance()->digitalWrite(EXT_PIN15_MOTOR_VIBRATE, HIGH);
    vTaskDelay(vibrate_time / portTICK_RATE_MS);
    IOExpander::instance()->digitalWrite(EXT_PIN15_MOTOR_VIBRATE, LOW);
}

//Global variables
//SPI bus configuration
SPIBus spibus;

//I2C bus configuration
I2CBus i2cbus;

//I2C Ext bus configuration
I2CBusExt i2cbusext;

ConfigManager *configManager = NULL;
Display *display = NULL;
IOExpander *ioExpander = NULL;
SDCard *_sdcard = NULL;
Buttons *buttons = NULL;
Power *power = NULL;
GPS*  gps = NULL;
IMU *imu = NULL;
Barometer *baro = NULL;

//Widgets (home)
Homescreen home;
Widget::SampleRate sampleWidget(Actions::ChangeSampleRate);
Widget::GyroRange gyroWidget(Actions::ChangeGyroRange);
Widget::AccelRange accelWidget(Actions::ChangeAccelRange);
Widget::SDFreeSpace sdfreespaceWidget;
Widget::Wifitransfer wifiWidget(Actions::WifiActions);
Widget::Battery batteryWidget;
Widget::GPS gpsWidget;
Widget::Log logWidget(Actions::IMUStartSD);
Widget::SD sdWidget(Actions::ToggleSD);
        
//Widgets (config)
Homescreen config;
Widget::SampleRate sampleWidget_c(Actions::ChangeSampleRate);
Widget::GyroRange gyroWidget_c(Actions::ChangeGyroRange);
Widget::AccelRange accelWidget_c(Actions::ChangeAccelRange);
Widget::SDFreeSpace sdfreespaceWidget_c;


void setup() {

  //disableCore0WDT();
  // put your setup code here, to run once:

  //This needs to be called first
  //install gpio isr service
  gpio_install_isr_service(0);

  //Set hardcoded timezone for now, TODO move somwhere else?
  setenv("TZ", "GEST+5EDT,M3.2.0/2,M11.1.0/2", 1);
  tzset();

  //Set time to JAN 1 2019
  struct tm tm;
  tm.tm_year = 2019 - 1900;
  tm.tm_mon = 0;
  tm.tm_mday = 1;
  tm.tm_hour = 1;
  tm.tm_min = 0;
  tm.tm_sec = 0;
  time_t t = mktime(&tm);

  printf("Setting time: %s", asctime(&tm));
  struct timeval my_time;
  my_time.tv_sec = t;
  my_time.tv_usec = 0;
  settimeofday(&my_time, NULL);

  //esp_err_t ret=0;

  //Get single instance of IOExpander...
  ioExpander = IOExpander::instance();

  //LED
  ioExpander->pinMode(EXT_PIN01_LED, OUTPUT);
  ioExpander->digitalWrite(EXT_PIN01_LED, HIGH);

  //BATT READ ENABLE
  ioExpander->pinMode(EXT_PIN13_BATT_READ_EN, OUTPUT);
  ioExpander->digitalWrite(EXT_PIN13_BATT_READ_EN, HIGH);

  //MOTOR VIBRATION
  ioExpander->pinMode(EXT_PIN15_MOTOR_VIBRATE, OUTPUT);
  ioExpander->digitalWrite(EXT_PIN15_MOTOR_VIBRATE, LOW);

  //ENABLE PROGRAMMING
  gpio_pad_select_gpio(PIN_NUM_ENABLE_PROGRAMMING);
  gpio_set_direction((gpio_num_t)PIN_NUM_ENABLE_PROGRAMMING, GPIO_MODE_OUTPUT);
  
  //PIN_NUM_ENABLE_PROGRAMMING = 
  //0 ---> CAN PROGRAM, 
  //1 ---> CANNOT PROGRAM WILL NOT RESET WHEN PLUGGING TO USB
  gpio_set_level((gpio_num_t)PIN_NUM_ENABLE_PROGRAMMING, 0);

  //Flashing Led Task
  TaskHandle_t ledBlinkHandle;
  xTaskCreate(&ledBlink, "Blinky", 2048, NULL, 1, &ledBlinkHandle);

  // SDCard must be started before configuration
  _sdcard = SDCard::instance();
  assert(_sdcard);

  // Configuration will read configuration from sdcard...
  configManager = ConfigManager::instance();
  assert(configManager);
  ConfigManager::instance()->print_configuration();

  //Mac Address
  uint8_t macaddress[6];
  uint64_t bit64macaddress[6];
  esp_read_mac(macaddress,ESP_MAC_WIFI_STA);
  for (int i=0;i<sizeof(macaddress);i++)
  {
      bit64macaddress[i]=macaddress[i];  
  }
  
  //Display
  display = Display::instance();
  assert(display);
  display->begin();
  display->showSplashScreen(bit64macaddress);
  TickType_t splashTime = xTaskGetTickCount();

  buttons = Buttons::instance();
  assert(buttons);

  power = Power::instance();
  assert(power);

  gps = GPS::instance();
  assert(gps);

  imu = IMU::instance();
  assert(imu);

  baro = Barometer::instance();
  assert(baro);

  //Pulse should be started from menu?
  //Not yet working...
  //Pulse *pulse = Pulse::instance();
  //assert(pulse);

  //Bluetooth *ble = Bluetooth::instance();
  //assert(ble);

  //Prototype WiFi transfer Agent
  WiFiTransfer *wifi = WiFiTransfer::instance();
  assert(wifi);

  //Widgets init
  batteryWidget.updateValue(5.0, 0.0, true);
  gpsWidget.setStatus(false);
  logWidget.setStatus(false,true);
  sdWidget.setStatus(false,true);

  //Setup home
  home.addWidget(&batteryWidget);
  home.addWidget(&gpsWidget);
  home.addWidget(&logWidget);
  home.addWidget(&sdWidget);
  home.addWidget(&wifiWidget);
  home.replaceSelection();

  // CONFIG SCREEN
  sampleWidget_c.setStatus(2);
  gyroWidget_c.setStatus(2);
  accelWidget_c.setStatus(2);
  sdfreespaceWidget_c.setStatus(16.0);
  config.addWidget(&sampleWidget_c);
  config.addWidget(&gyroWidget_c);
  config.addWidget(&accelWidget_c);
  config.addWidget(&sdfreespaceWidget_c);
  config.replaceSelection();
  config.setVisible(false);

  // Show homescreen and disable programming
  vTaskDelayUntil(&splashTime, 4200 / portTICK_RATE_MS);
  VibrateMotor(400);
 
  home.setVisible(true);

  //Intialise counter  for message of widget
  Actions::SampleRateCounter = IMU::instance()->getSampleRate();
  Actions::GyroRangeCounter = IMU::instance()->getGyroRange();
  Actions::AccelRangeCounter = IMU::instance()->getAccelRange();
}

TickType_t lastBtn = xTaskGetTickCount();
TickType_t lastRefresh = xTaskGetTickCount();
TickType_t now;
bool active = false;
bool configscreen = false;
bool _batteryLowMode = false;


void loop() {


  // put your main code here, to run repeatedly:
  //printf("%f %f \n", voltage, current);


  // Sleep for 100ms
  vTaskDelay(150 / portTICK_RATE_MS);

  //Check battery state

  if(power->last_voltage()<3.2)
  {
      _batteryLowMode = true;
  }
  else if (power->last_voltage()>3.3)
  {
      _batteryLowMode = false;
  }

  // Check buttons

  while(buttons->getActionCtn() > 0) 
  {
      if (active && !_batteryLowMode) 
      {
          if (home.getVisible())
          {
              home.action();
          }

          if (config.getVisible())
          {
              config.action();
          }
      }
      buttons->decrementActionCtn();
      lastBtn = xTaskGetTickCount();
  }

  while(buttons->getPreviousCtn() > 0) 
  {
      if (active && !_batteryLowMode) 
      {
          if (home.getVisible())
          {
              home.previous();
          }

          if (config.getVisible())
          {
              config.previous();
          }
      }
      buttons->decrementPreviousCtn();
      lastBtn = xTaskGetTickCount();
  }

  while(buttons->getNextCtn() > 0) 
  {
      if (active && !_batteryLowMode) 
      {
          if (home.getVisible())
          {
              home.next();
          }

          if (config.getVisible())
          {
              config.next();
          }
      }
      buttons->decrementNextCtn();
      lastBtn = xTaskGetTickCount();
  }

  while(buttons->getBackCtn() > 0) 
  {
      if (active && !configscreen && !_batteryLowMode)
      {  
          config.replaceSelection();
          home.setVisible(false);
          config.setVisible(true);
          configscreen = true;

          VibrateMotor(300);
      }

      else if (active && configscreen && !_batteryLowMode)
      {  
          home.replaceSelection();
          config.setVisible(false);
          home.setVisible(true);
          configscreen = false;

          VibrateMotor(300);
      }
      buttons->decrementBackCtn();
      lastBtn = xTaskGetTickCount();
  }

  //Update widgets state (home)
  batteryWidget.updateValue(power->last_voltage(), power->last_current(), power->last_charging());
  gpsWidget.setStatus(gps->getFix());
  logWidget.setStatus(Actions::loggingEnabled,SDCard::instance()->getSdCardPresent());
  sdWidget.setStatus(Actions::sdcardExternal,SDCard::instance()->getSdCardPresent());
  sampleWidget.setStatus(Actions::SampleRateCounter);
  gyroWidget.setStatus(Actions::GyroRangeCounter);
  accelWidget.setStatus(Actions::AccelRangeCounter);
  sdfreespaceWidget.setStatus(SDCard::instance()->getSDfreespace());
  wifiWidget.setStatus(WiFiTransfer::instance()->getStateString());

  //Update widgets state(config)
  sampleWidget_c.setStatus(IMU::instance()->getSampleRate());
  gyroWidget_c.setStatus(IMU::instance()->getGyroRange());
  accelWidget_c.setStatus(IMU::instance()->getAccelRange());
  sdfreespaceWidget_c.setStatus(SDCard::instance()->getSDfreespace());
  


  //Check logging status
  if (Actions::loggingEnabled && !Actions::wasLogging)
  {
      home.startLog(-1);
      home.setLogID(SDCard::instance()->getlogID());
  }
  else if (!Actions::loggingEnabled && Actions::wasLogging)
  {
      home.stopLog();
  }
  Actions::wasLogging = Actions::loggingEnabled;

  // Check activity
  now = xTaskGetTickCount();
  if (now-lastBtn > SCREEN_SLEEP_TIMER/portTICK_RATE_MS)
  {
      display->setBrightness(Display::Brigthness::SLEEP);
      active = false;
  }
  else if (now-lastBtn > SCREEN_DIM_TIMER/portTICK_RATE_MS)
  {
      if (active) display->setBrightness(Display::Brigthness::DIM);
      active = false;
  }
  else {
      if (!active) display->setBrightness(Display::Brigthness::NORMAL);
      active = true;
  }

  // Update time and battery mode each second
  if (now-lastRefresh > 1000/portTICK_RATE_MS)
  {
      if (home.getVisible())
      {
          home.updateBatteryMode(_batteryLowMode);
          home.setVisible(true);
          lastRefresh = now;
      }

      if (config.getVisible())
      {                   
          config.updateBatteryMode(_batteryLowMode);
          config.setVisible(true);
          lastRefresh = now;
      }
  }

  
}

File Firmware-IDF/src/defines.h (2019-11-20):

#ifndef _DEFINES_H_
#define _DEFINES_H_

#include <stdint.h>
#include <string>

/**
 * Put global definitions here
 * 
 **/

//MAX30102 definitions
#define MAX30102_FIFO_SIZE 32 
#define PULSE_BUFFER_LENGHT 100


typedef struct {
    float accelX;
    float accelY;
    float accelZ;
    float gyroX;
    float gyroY;
    float gyroZ;
    float magX;
    float magY;
    float magZ;
} imuData_t;
typedef imuData_t* imuDataPtr_t;

typedef struct {
    float voltage;
    float current;
} powerData_t;
typedef powerData_t* powerDataPtr_t;


typedef struct {
    float temperature;
    float pressure;
} baroData_t;
typedef baroData_t* baroDataPtr_t;


typedef struct {
    bool fix;
    float latitude;
    float longitude;
    float altitude;
} gpsData_t;
typedef gpsData_t* gpsDataPtr_t;


typedef struct {
    uint32_t ir_led_data[PULSE_BUFFER_LENGHT];
    uint32_t red_led_data[PULSE_BUFFER_LENGHT];
    float spo2;
    int heartrate;
} pulseData_t;
typedef pulseData_t* pulseDataPtr_t;

typedef struct {
    int IMUSampleRate;
    int IMUGyroRange;
    int IMUAcellRange;
}  IMUconfig_Sd;
//typedef IMUconfig_Sd* IMUconfigPtr_Sd;

typedef struct {
    std::string deviceName;
    std::string openTeraServerName;
    int openTeraServerPort;
    std::string openTeraToken;
} OpenTeraConfig_Sd;

typedef struct {
    std::string ssid;
    std::string password;
} WiFiConfig_Sd;


#ifndef OUTPUT
#define OUTPUT (0)
#endif

#ifndef INPUT
#define INPUT (1)
#endif

#ifndef HIGH
#define HIGH (1)
#endif

#ifndef LOW
#define LOW (0)
#endif

#ifndef ON
#define ON (1)
#endif

#ifndef OFF
#define OFF (0)
#endif


//I/O Expander pins (id is +1 of index)
#define EXT_PIN00_DISPLAY_RESET 1
#define EXT_PIN01_LED 2
#define EXT_PIN02_BUTTON0 3
#define EXT_PIN03_SD_N_ENABLED 4
#define EXT_PIN04_SD_N_CD 5
#define EXT_PIN05_SD_SEL 6
#define EXT_PIN06_BUTTON1 7
#define EXT_PIN07_VUSB 8
#define EXT_PIN08_BUTTON2 9
#define EXT_PIN09_BUTTON3 10
#define EXT_PIN10_CHARGING 11
#define EXT_PIN11_UNUSED 12
#define EXT_PIN12_P5_PIN7 13
#define EXT_PIN13_BATT_READ_EN 14
#define EXT_PIN14_EXTERNAL_POWER_EN 15
#define EXT_PIN15_MOTOR_VIBRATE 16

#define IO_EXPANDER_PIN_NUM_CS   5

//SPI definitions
#define PIN_NUM_MISO 39
#define PIN_NUM_MOSI 18
#define PIN_NUM_CLK  19

//I2C definitions
#define PIN_NUM_SDA 23
#define PIN_NUM_SCL 25

//GPS definitions
#define PIN_NUM_UART_TX 26 
#define PIN_NUM_UART_RX 35

//I2C definitions EXT
#define PIN_NUM_EXTSDA 17
#define PIN_NUM_EXTSCL 16

//ADC definitions
#define PIN_NUM_ADC_READY 33
#define ADC_VOLTAGE_CHANNEL 0
#define ADC_CURRENT_CHANNEL 1
#define ADC_THERM_CHANNEL 2

//Display definitions
#define PIN_NUM_DISPLAY_RESET EXT_PIN00_DISPLAY_RESET
#define PIN_NUM_DISPLAY_CS 21
#define PIN_NUM_DISPLAY_DC 22

// System definitions
#define PIN_NUM_ENABLE_PROGRAMMING 27
#define SCREEN_DIM_TIMER 5000
#define SCREEN_SLEEP_TIMER 15000

#endif

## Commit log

2018-03-22 IMU interface working
2018-03-22 IMU logs to Queue
2018-03-27 Moved display RST and DC to gpio expander. Added an i2c mutex class.
2018-03-28 Added timestamp to log. Time is synchronized on GPS fix.
    [gps.cpp, main.cpp, sdcard.cpp]
2018-03-28 Now using interrupt pin on IMU to reduce i2c traffic induced by polling for ready.
2018-04-03 Bug fix when starting and stopping SD log
    [gps.cpp, main.cpp, sdcard.cpp]
2018-04-19 Added FIFO project, interrupt for IMU and semaphore for SD log
2018-04-20 Changed IMU library in FIFO project for better FIFO support (added mag support)
2018-04-20 WIP new IMU lib for FIFO in firmware project.
2018-05-04 starting board working
2018-05-07 working I2C + MPU9250
2018-05-07 fixed sdcard driver
2018-05-07 working buttons
2018-05-09 mutex problem to be fixed
    [main.cpp]
2018-05-16 Fixed SPI lock sequence
    [main.cpp]
2018-05-16 IMU now starting properly
2018-05-16 shutting down, but will not ever be able to power up again
2018-05-17 added ADC library
2018-05-17 reading batt voltage and current
2018-05-17 fixed buttons logic
2018-05-17 working voltage
2018-05-19 changed board to esp32dev, closer to our setup
2018-05-20 not reading from FIFO, values were not correct
    [gps.cpp, imu.cpp, main.cpp]
2018-05-20 cleaning up IMU code
2018-05-21 writing power values to log
2018-05-25 Added Solidworks files and STL files
    [Back Cover R2.SLDPRT, Back Cover R2.STL, Bouton Open MU.SLDPRT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]
2018-05-28 PCB - initial commit.
    [ADC.SchDoc, Display.SchDoc, MCU.SchDoc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]
2018-05-29 Update Display and RTC
    - Synchronize device time on GPS RTC at init
    - Menu Updated
    - Sleep Screen Updated
    - Buttons Updated
2018-05-30 changed I2C init
2018-05-31 added cas and pcb images
2018-06-02 Moved all tasks on core 1 (arduino) except i2c tasks on core 0
2018-06-03 Flushing file, setup i2c speed to 100000
2018-06-03 reactivated imu
2018-06-04 Modified automatic output settings (PDF schematic filename; color PDF) Added Introlab open source markings on top level schematic sheet
    [OpenIMU.PrjPcb, TopLevel.SchDoc]
2018-06-04 Modified automatic output PDF settings (filename, color) Added Open HW markings on top level schematics
    [OpenIMU.PrjPcb, TopLevel.SchDoc]
2018-06-04 Modified automatic PDF generation settings (color; filename) Added open hardware markings to top level schematics
    [OpenIMU.PrjPcb, TopLevel.SchDoc]
2018-06-05 Added PCB schematics
2018-06-05 Minor corrections in schematic text notes
    [Display.SchDoc, TopLevel.SchDoc]
2018-06-05 Minor corrections in schematic text notes for readability
    [Display.SchDoc, Sensors.SchDoc]
2018-06-08 init spi bus
2018-06-13 digital Read implemented, but not working yet
    [ioexpander.cpp, main.cpp]
2018-06-14 init spi and i2c working
2018-06-14 working adc
2018-06-14 strange values from adc converter
2018-06-15 waiting for conversion completed interrupt in adc
2018-06-15 working adc conversion to voltage / current
2018-06-15 working SPI bus locking mechanism
2018-06-19 added led blink task
2018-06-20 implementation of i2c bus
2018-06-20 init i2c bus
2018-06-20 working I2Cbus driver, thread safe
2018-06-20 something is wrong with compilation
    [imu.cpp, imu.h]
2018-06-21 fixed values from mpu9250, implementation needs work
    [imu.cpp, main.cpp]
2018-06-21 starting sdcard driver
2018-06-21 IMU reading task working
2018-06-21 reading data to imu structure
2018-06-22 working imu data sending to log task
2018-06-22 moved adc code to ADS1015 library
2018-06-22 moved ADC->Power
2018-06-22 sending power data to log
2018-06-22 working MPL115A2 driver
2018-06-28 sending gps data to logging thread, gps now singleton
2018-06-29 Buttons implementation
2018-06-29 added volt/current values to display
2018-06-29 fixed time update when no GPS fix
    [gps.cpp]
2018-06-29 added GPS fix flag
    [gps.cpp, main.cpp]
2018-06-29 feature complete with arduino firmware, needs testing
2018-06-29 fixed nasty interrupt delay problem with the watchdog
    [main.cpp, sdcard.cpp]
2018-06-29 not starting logging by default, display mac address correctly
    [main.cpp]
2018-06-30 increased delay to read conversion from baro, updated i2c read commands
2018-07-15 moved Firmware to Firmware-Arduino
2018-07-19 fixed serial port setup for arduino
    [sdcard.cpp]
2018-08-27 generateTimestamp added to replace interrupt form GPS
    GPS can deliver 1 Hz signal but it is dependant of the signal quality
    [sdcard.cpp]
2018-11-06 Fixed delay when ready GPS
    [gps.cpp]
2018-11-06 fixed RTPS timing, 1000Hz
2019-04-12 added pulse sensor, not yet working
2019-04-15 fixed timestamp, testing eddystone
    [gps.cpp, main.cpp]
2019-07-04 Add SSD1331 display driver library and adapt it to esp_idf. SPI configuration not working.
    [defines.h, main.cpp]
2019-07-08 Make SSD131 driver work
2019-07-11 Change FREE RTOS frequency to 1000 Hz
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2019-07-12 Switch to one shot frame buffer write
2019-08-12 Add support for new OLED screen and replace menu by homescreen
    [buttons.cpp, defines.h, gps.cpp]
2019-08-13 Remove charging battery message Update homescreen with logging status
2019-08-13 Add vibration on boot
    [main.cpp]
2019-08-13 Add debug print to imu
2019-08-20 V2 (new screen LCD instead of e-ink, added power switch, modified expansion connector, added switches for enabling/disabling programming)
    [Display.SchDoc, MCU.SchDoc, OpenIMU.PrjPcb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]
2019-09-18 Changed display from e-ink to OLED. Added I2C resistors. Patched USB-SD card switch CS detection signal. Added power button.
    [Display.SchDoc, MCU.SchDoc, OpenIMU.PrjPcb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]
2019-10-04 Retry to initialize IMU, give RST more time, allow prog at boot.
2019-10-09 Tracking IMU init problem, not resolved
    [imu.cpp]
2019-10-16 Testing new IMU library
2019-10-22 Added pin 1 of accelerometer to net +3V3
    [OpenIMU.PrjPcb, Sensors.SchDoc]
2019-10-28 See description for changes
    New IMU Library implemented
    Config Screen added
    Sample Rate changeable on device
    Config file on SD Card for initial parameter
    Logger no longer crashes when trying to start logging without SD Card
    Pedometer added on Config Screen
2019-10-28 See description for information
    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
    [defines.h, icons.h, imu.cpp]
2019-11-01 CAD Updated with new case
    [90190A024_PAN HEAD PHILLIPS SCREW FOR SHEET METAL.SLDPRT, Back Cover R2.SLDPRT, Back Cover R2.STL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]
2019-11-01 Added Qt config App
    [Ecran.SLDPRT]
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2019-11-04 Load and save file to JSON format, register device to OpenTera Server
2019-11-05 Update CAD with bigger screws
    [90190A024_PAN HEAD PHILLIPS SCREW FOR SHEET METAL.SLDPRT, 92525A118_THREAD-FORMING SCREW FOR SHEET METAL IRON.SLDPRT, Back Cover R2.SLDPRT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]
2019-11-05 Working JSON read for IMU
2019-11-05 Testing WiFi, brownout detected will require a 500mA regulator
    [gps.cpp, main.cpp, sdcard.cpp]
2019-11-06 Creating log directory, saving json with configuration, saving configuration when samplerate changes
2019-11-11 Added Gyro Range, Accel Range, Modified README file
2019-11-15 SDCard free space Widget
    [90190A024_PAN HEAD PHILLIPS SCREW FOR SHEET METAL.SLDPRT]
2019-11-18 Fixed 3v3 power supply, wifi working
    [main.cpp, power.cpp]
2019-12-09 Battery Low screen,Wifi disabled, Initialise empty SDcard
    [Back Cover R2.SLDPRT, Back Cover R2.STL, Top Cover.SLDPRT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]
2020-04-16 Working Arduino version, starting wifi.
2020-04-21 Put back CPU @ 80MHz, update main loop at 150ms, allows WiFi and IMU to operate properly.
2022-08-23 Fixed arduinoexpressif version to 3.5
    [sdcard.cpp]
